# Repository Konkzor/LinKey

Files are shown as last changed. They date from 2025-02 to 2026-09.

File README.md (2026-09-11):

<p align="center">
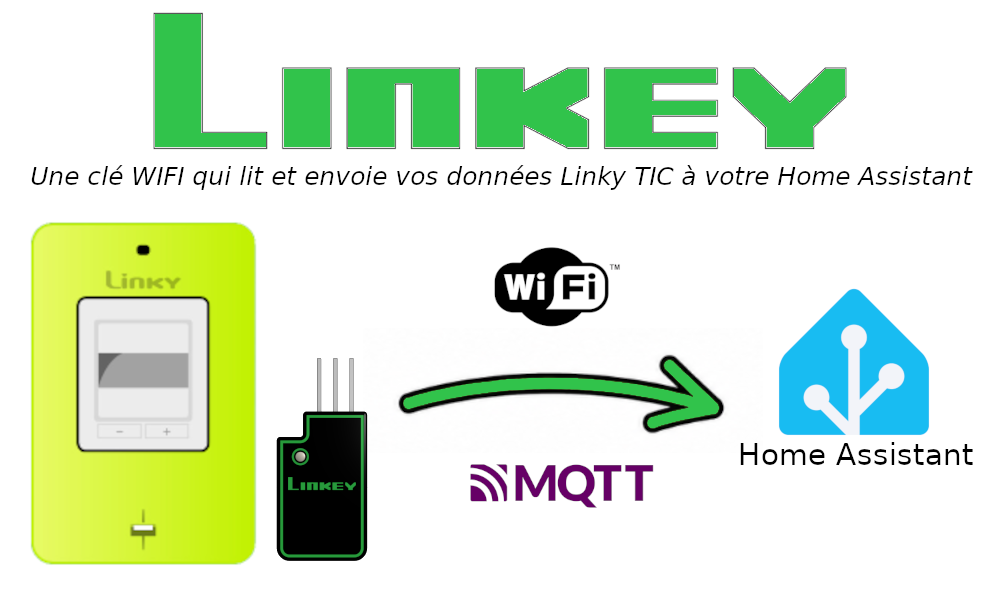
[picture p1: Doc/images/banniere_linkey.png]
Logo Linkey
  
</p>







Moniteur **open-hardware** basse consommation à base d'ESP32 pour le compteur électrique **Linky** (monophasé), avec intégration native à **Home Assistant** via MQTT.

LinKey (jeu de mot) lit la sortie série TIC (Télé-Information Client) d'un Linky monophasé et publie les mesures de puissance, d'énergie et de courant vers le broker MQTT de votre Home Assistant. Le coprocesseur ULP de l'ESP32 décode la trame TIC pendant que le CPU principal reste en *light sleep*, ce qui maintient une consommation moyenne suffisamment faible pour fonctionner sur l'alimentation de la TIC via une supercapa.

## Fonctionnalités

- Décodage UART 7E1 (1200 bauds) par le coprocesseur ULP de l'ESP32
- Boucle principale en *light sleep* avec *modem sleep* WiFi
- Publication MQTT en QoS 1, *Last Will and Testament* et auto-découverte Home Assistant
- Alimentation par supercapa avec surveillance de tension intégrée
- Retour visuel par LED RGB
- Compatible contrats BASE, HP/HC, Tempo et EJP
- Mode TIC historique (standard à venir)

## Structure du dépôt

```
.
├── CAO/        Boîtier imprimable 3D (source STEP + modèle Onshape)
├── Doc/        Spécification TIC Linky et documents de référence
├── Firmware/   Projet ESP-IDF (ULP + machine d'état CPU, WiFi/MQTT)
└── PCB/        Projet KiCad, schéma, Gerbers

```

## Documentation

- [Guide du firmware](Firmware/README.md) — compilation, flashage, configuration, topics MQTT, découverte HA
- [Guide de la carte (PCB)](PCB/README.md) — composants, brochage ESP32, connexion TIC, fabrication
- [Guide du boîtier (CAO)](CAO/README.md) — source Onshape, STEP, paramètres d'impression
- [Spécification TIC Linky](Doc/Enedis-MOP-CPT_002E.pdf) — document de référence Enedis

## Firmware

Le firmware est un projet ESP-IDF situé dans [`Firmware/`](Firmware/). Consultez [`Firmware/README.md`](Firmware/README.md) pour le guide complet de compilation, flashage et configuration.

Démarrage rapide :

```bash
git clone --recurse-submodules https://github.com/Konkzor/LinKey.git
cd LinKey/Firmware
source ~/esp/v5.4.1/esp-idf/export.sh
idf.py menuconfig    # Configurer l'appareil et les options MQTT
idf.py -p /dev/ttyUSB0 flash monitor
```

Les identifiants WiFi sont provisionnés ensuite en BLE via l'application Espressif. Le firmware tente de découvrir Home Assistant en mDNS pour construire automatiquement l'URI MQTT (`mqtt://<ha-ip>:1883`), puis utilise `mqtt://homeassistant.local:1883` comme solution de repli.

L'identité MQTT par défaut est dérivée de l'adresse MAC WiFi : utilisateur `linkey_<suffixe_mac>` et topics `linkey/<suffixe_mac>/...`, par exemple `linkey/8ebde0/state`.

## PCB

Le PCB a été réalisé sous KiCad 9.

<p align="center">
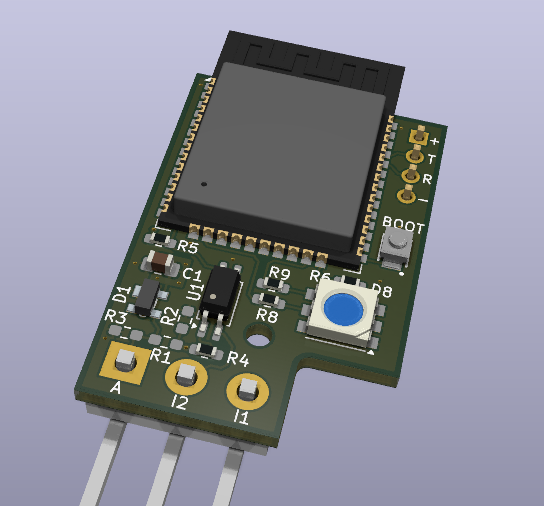
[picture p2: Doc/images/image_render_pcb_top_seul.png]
Rendu 3D de la carte LinKey
  
</p>

Les sources de la carte se trouvent dans [`PCB/`](PCB/). Voir [`PCB/README.md`](PCB/README.md) pour une description des composants, le brochage de l'ESP32 et la connexion TIC.

- Projet KiCad : [`PCB/LinKey.kicad_pro`](PCB/LinKey.kicad_pro)
- Modèles 3D de certains composants : [`PCB/MCAD files/`](PCB/MCAD%20files/)

> Note : Les fichiers de fabrication et la nomenclature ne sont pas versionnés dans le repo. Ils sont disponibles en artefacts des jobs de la CI ainsi que dans la [page Releases](https://github.com/Konkzor/LinKey/releases) pour les versions taguées.

## CAO

Le boîtier est conçu sous Onshape et imprimable en 3D.

<p align="center">
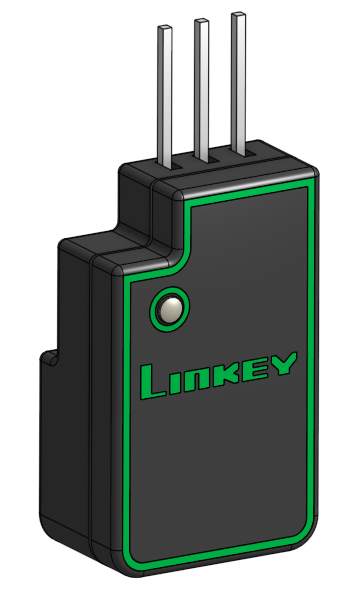
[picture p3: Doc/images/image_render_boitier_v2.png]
Rendu 3D du boîtier LinKey v2
  
</p>

Les sources se trouvent dans [`CAO/`](CAO/). Voir [`CAO/README.md`](CAO/README.md) pour le lien vers le modèle Onshape et les paramètres d'impression conseillés.

- Source CAO neutre (STEP) ;
- Fichiers prêts à imprimer (3MF multicolore, STL mono-couleur) : [page Releases](https://github.com/Konkzor/LinKey/releases).

## Licence

Ce projet utilise une **double licence** selon la nature des fichiers :

### Matériel — CERN-OHL-W-2.0

Le matériel (`PCB/` : sources KiCad, Gerbers… et `CAO/` : modèles 3D du boîtier, pièces mécaniques) est distribué sous **CERN Open Hardware Licence Version 2 – Weakly Reciprocal (CERN-OHL-W-2.0)**.

Vous êtes libre d'utiliser, d'étudier, de modifier et de fabriquer ce matériel.
Si vous modifiez les fichiers de conception eux-mêmes, vous devez publier ces modifications sous la même licence.
En revanche, vous n'êtes pas tenu de publier les sources de produits plus larges qui ne font qu'incorporer cette conception.

Texte complet : [`LICENSE`](LICENSE) (EN).

### Firmware — MIT

Le code du firmware (`Firmware/main/`) est distribué sous **licence MIT**, plus permissive et adaptée au logiciel.

Texte complet : [`Firmware/LICENSE`](Firmware/LICENSE) (EN).

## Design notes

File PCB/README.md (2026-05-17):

# LinKey — Carte électronique

<p align="center">
  Rendu 3D de la carte LinKey
</p>

Sources matérielles de la carte LinKey : projet KiCad, Gerbers et nomenclature.

> [!NOTE]
> La révision PCB est portée par les **tags git** `pcb-v*` (ex. `pcb-v1.0`). C'est la **source unique** : la CI dérive la version d'`git describe --tags --match 'pcb-v*'` et l'injecte à la fois dans le nom de l'artefact (`LinKey-pcb-<version>-fab`) et dans la variable de projet `PCB_VERSION` (Board Setup → Text Variables) pour que la sérigraphie `${PCB_VERSION}` reflète exactement l'état du dépôt :
>
> | Build | `${PCB_VERSION}` et nom d'artefact |
> |-------|------------------------------------|
> | Local (export manuel depuis KiCad) | `UNCONTROLLED` — valeur fixée en dur dans [`LinKey.kicad_pro`](LinKey.kicad_pro), signale que les fichiers de fab n'ont pas été produits par la CI et ne doivent pas être utilisés |
> | CI hors tag | `vX.Y-N-gSHA` (tag le plus récent + commits depuis + hash court) |
> | CI sur un tag `pcb-vX.Y` | `vX.Y` |

## Couche physique de la TIC Linky

> Source : [Enedis-NOI-CPT_54E](../Doc/Enedis-MOP-CPT_002E.pdf), §5.3.1 *Caractéristiques des signaux* (Table 3).

La sortie TIC du compteur Linky se présente sur le bornier client sous forme de **trois bornes** (`I1`, `I2`, `A`) : la paire `I1`/`I2` véhicule les **données**, et la paire `I1`/`A` est dédiée à l'**alimentation parasite** des récepteurs. Le compteur émet sur ce bus un **signal binaire modulé par tout-ou-rien sur une porteuse 50 kHz ± 3 %** (Table 3 de la spec Enedis), avec une **logique de codage négative** (porteuse présente ⇒ « 0 », porteuse absente ⇒ « 1 ») et une transmission **unidirectionnelle**.

<p align="center">
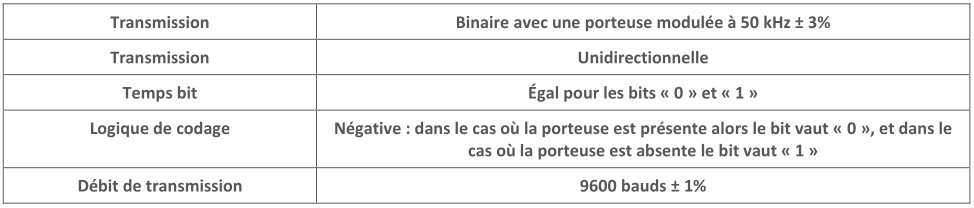
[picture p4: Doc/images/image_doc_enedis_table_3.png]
Enedis — Table 3 : Caractéristiques des signaux
  
</p>

> [!WARNING]
> Bien que les niveaux soient bas, le bus TIC reste relié au compteur — une **isolation galvanique côté récepteur reste obligatoire** pour la sécurité utilisateur et la conformité. C'est le rôle de l'optocoupleur (voir l'étage d'entrée ci-dessous).

Le bus est connecté à la carte via le connecteur **`J1`** (Samtec **HPM-03-04-T-S**, header 3 broches, pas 5 mm, sortie à angle droit).

## Architecture du PCB

L'architecture du PCB est composée de 2 branches principales :

```mermaid
flowchart LR
    TIC([TIC Linky J1<br/>I1, I2, A])

    TIC -->|I1 / A| D1[Pont redresseur<br/>D1]
    D1 --> Charge[Circuit de charge<br/>Q1, Q2, U4]
    Charge --> C2[(C2 — 1 F<br/>supercapa)]
    C2 --> Boost[Boost 3,3 V<br/>U5 — TPS61022]
    Boost --> ESP[ESP32 WROOM-32E<br/>+ périphériques]

    TIC -->|I1 / I2| U1[Opto AC/DC<br/>U1 — ACPL-214]
    U1 -->|RX — GPIO 14| ESP

    C2 -.->|ADC GPIO 33 — V_cap| ESP
```

- **Branche supérieure** : chemin d'alimentation, sur les bornes **`I1` / `A`** du Linky → pont redresseur → circuit de charge supercapa → `C2` → boost 3,3 V → ESP32.
- **Branche inférieure** : chemin de données, sur les bornes **`I1` / `I2`** du Linky → optocoupleur → ESP32.

Remarque : En **trait pointillé** la mesure de la tension du supercondensateur par l'ESP32.

### 1. Étage d'entrée

Sépare et conditionne les deux fonctions du bus TIC.

- **Démodulation des données** — `U1` (Broadcom **ACPL-214-500E**, opto **AC** SOP-4) extrait directement l'enveloppe de la porteuse 50 kHz et fournit un signal UART démodulé côté ESP32 (pull_up `R5` incluse), tout en assurant l'isolation galvanique.
- **Pont redresseur d'alimentation** — `D1` (Infineon **BAS 4002A RPP E6327**, array de Schottky basse Vf) forme un pont à quatre diodes dans un seul boîtier qui rectifie la porteuse 50 kHz pour alimenter le reste de la carte.

<p align="center">
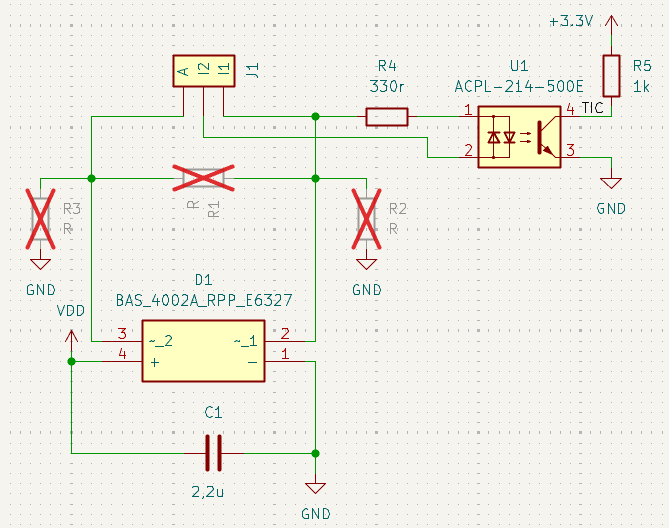
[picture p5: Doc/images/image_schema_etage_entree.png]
Schéma de l'étage d'entrée (opto + pont redresseur)
  
</p>

### 2. Circuit de charge du supercondensateur

Stocke l'énergie disponible pour absorber les pics de consommation pendant l'émission WiFi/MQTT. Limite le courant et la tension de charge.

- **Supercondensateur** — `C2` (KYOCERA AVX **SCCR12E105SRB**, 1 F / 3 V, ESR faible, radial 8×12 mm).
- Limitation de courant et tension contrôlant la tension Vgs de `Q2` (TI **CSD25402Q3A**, P-MOSFET 20 V) :
  - **Limitation de courant** — `Q1` (ON Semi **MMBT2907A**, PNP 60 V / 0,6 A) conjugué à `R10` (10 Ω) qui fixe le seuil de courant débité par l'étage d'entrée vers la supercapa à environ  40 mA.
  - **Limitation de tension** — `U4` (TI **TL431**, référence shunt ajustable) clampe la tension de charge à 2,7V de la supercapa (seuil réglé par `R15` et `R16`).

<p align="center">
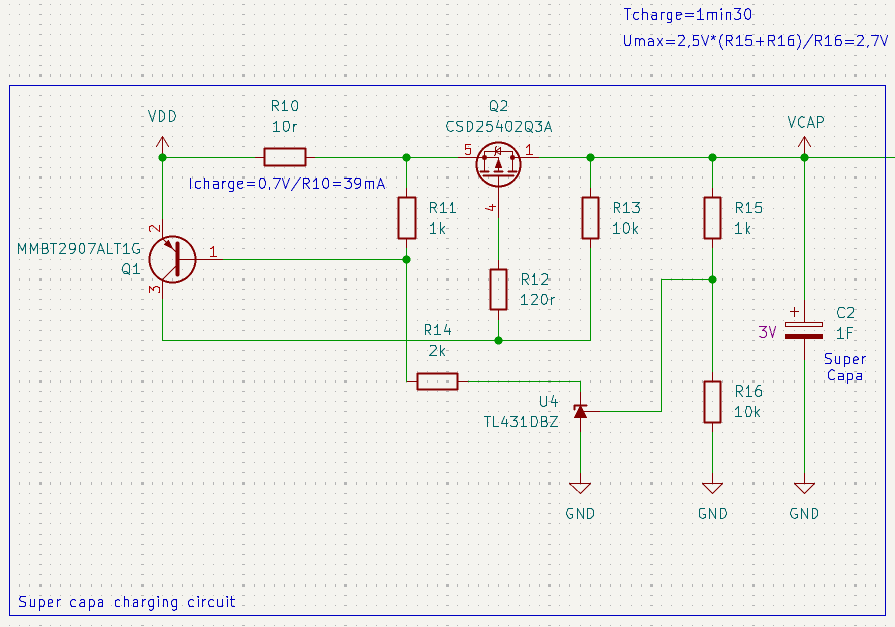
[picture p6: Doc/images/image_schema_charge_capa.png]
Schéma du circuit de charge du supercondensateur
  
</p>

### 3. Alimentation 3,3 V (boost)

Convertit la tension variable du supercondensateur (0 V → 2,7 V) en un rail 3,3 V stable pour l'ESP32.

- **Convertisseur** — `U5` (TI **TPS61022**, boost synchrone 8 A pic, **démarrage à 1,5 V, maintien jusqu'à 0,5 V**) : on peut tirer du jus de la supercapa presque jusqu'à le vider complètement.
- **Inductance** — `L1` (Coilcraft **XEL5030-102MEC**, 1 µH), recommandée par TI.
- **Capacités** — `C3`, `C4` pour l'entrée, `C6` (22 µF / 10 V X7R 1206) pour la sortie.
- **Pont diviseur** — `R17` (453 k) / `R18` (100 k) pour régler la sortie à 3,3 V.

<p align="center">
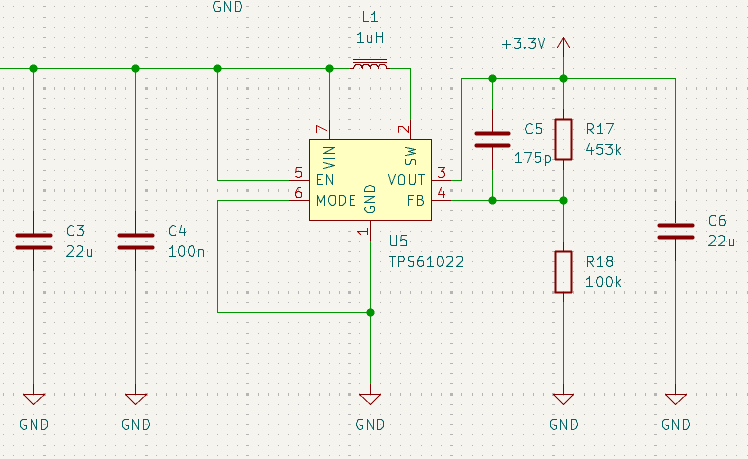
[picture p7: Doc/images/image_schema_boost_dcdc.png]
Schéma du convertisseur boost 3,3 V (TPS61022)
  
</p>

### 4. ESP32 et périphériques

- **MCU** — `U2` (Espressif **ESP32-WROOM-32E-N8**, 8 MB flash SPI, antenne PCB intégrée). Module choisi pour sa disponibilité du **coprocesseur ULP** que le firmware utilise pour décoder la TIC pendant le *light sleep*.
- **Découplage** — `C8` (100 nF), `C7` (22 µF).
- **Interface programmation/debug** — `J2` (header 4 broches, pas 2,54 mm) expose `TX`, `RX`, `GND`, `3V3` pour le flashage et le debug.
- **Boutons** — deux boutons tactiles Omron **B3U-1000P** :
  - `SW1` — **RESET**, raccordé sur la broche `EN` de l'ESP32 (tient le module en reset tant qu'il est pressé).
  - `SW2` — **BOOT**, raccordé sur `IO0` ; à maintenir pendant un reset pour entrer en mode flashage.
- **LED d'état RGB** — `D8` (American Bright **BL-HBXJXGX32L**, 5050 PLCC6) avec ses résistances de limitation `R6` (120 Ω) / `R8` (330 Ω) / `R9` (120 Ω) sur les trois canaux B/R/G respectivement. Pilotée par GPIO 2 / 13 / 15 ; flash bref de 10 ms à chaque itération de la FSM (voir `Firmware/README.md`).

<p align="center">
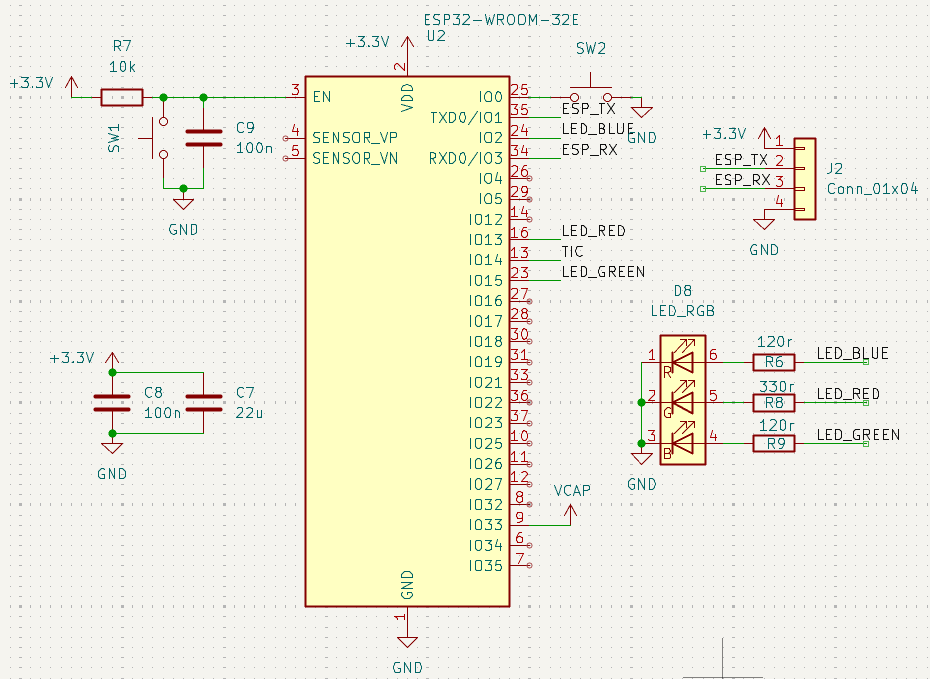
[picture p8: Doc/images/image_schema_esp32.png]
Schéma de l'ESP32 et de ses périphériques (LED RGB, bouton, header debug)
  
</p>

## Affectation des broches (ESP32)

| Fonction | GPIO |
|---|---|
| RX TIC Linky | 14 |
| ADC tension supercondensateur | 33 |
| LED RGB Rouge | 13 |
| LED RGB Verte | 15 |
| LED RGB Bleue | 2 |
| RX UART ESP | 3 |
| TX UART ESP | 1 |

## Contenu du dossier

| Fichier / dossier | Description |
|---|---|
| [`LinKey.kicad_pro`](LinKey.kicad_pro) | Projet KiCad 9 |
| [`LinKey.kicad_sch`](LinKey.kicad_sch) | Schéma |
| [`LinKey.kicad_pcb`](LinKey.kicad_pcb) | Routage |
| [`fab-output.kicad_jobset`](fab-output.kicad_jobset) | Jobset KiCad décrivant les sorties de fabrication générées en CI |
| [`MCAD files/`](MCAD%20files/) | Modèles 3D des composants (STEP) |
| [`LinKey_Lib_Footprints.pretty/`](LinKey_Lib_Footprints.pretty/) | Bibliothèque d'empreintes du projet |
| [`LinKey_Lib_Symbols.kicad_sym`](LinKey_Lib_Symbols.kicad_sym) | Bibliothèque de symboles du projet |

## Fabrication

Les fichiers de fabrication ne sont **pas versionnés** : ils sont régénérés à chaque push par le workflow GitHub Actions [`.github/workflows/ci.yml`](../.github/workflows/ci.yml) (job `pcb-fab`) à partir du jobset [`fab-output.kicad_jobset`](fab-output.kicad_jobset), et publiés en tant qu'artefact nommé **`LinKey-pcb-<PCB_VERSION>-fab`** sur l'exécution correspondante (la version provient de la variable de projet `PCB_VERSION` — cf. note en haut de ce README).

Contenu de l'artefact :

| Fichier | Description |
|---|---|
| `gerbers/LinKey-F_Cu.gbr`, `B_Cu.gbr`, `In1_Cu.gbr`, `In2_Cu.gbr` | Couches cuivre (4 couches) |
| `gerbers/LinKey-F_Mask.gbr`, `B_Mask.gbr` | Masques de soudure |
| `gerbers/LinKey-F_Paste.gbr`, `B_Paste.gbr` | Pochoir pâte à braser |
| `gerbers/LinKey-F_Silkscreen.gbr`, `B_Silkscreen.gbr` | Sérigraphies |
| `gerbers/LinKey-Edge_Cuts.gbr` | Contour de la carte |
| `gerbers/LinKey-job.gbrjob` | Métadonnées Gerber X2 (stackup) |
| `LinKey-PTH.drl`, `LinKey-NPTH.drl` | Perçages (plaqués / non plaqués) |
| `LinKey_positions-all.csv` | Fichier de positions (pick & place) |
| `LinKey_Bill_of_Materials.csv` | Nomenclature (BOM) |

Pour récupérer l'archive : ouvrir l'exécution CI sur GitHub → onglet *Summary* → section *Artifacts* → **`LinKey-pcb-<PCB_VERSION>-fab`**.

## Consommation

- ***Light sleep*** : à mesurer
- **Actif (publication)** : à mesurer
- **Moyenne** : à mesurer

## Licence

Voir le fichier [LICENSE](../LICENSE) à la racine du dépôt (CERN-OHL-W-2.0).

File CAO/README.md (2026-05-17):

# LinKey — Boîtier

<p align="center">
  Rendu 3D du boîtier LinKey v2
</p>

Boîtier imprimable en 3D pour la carte LinKey.

## Source du modèle

Le boîtier est conçu et versionné sous **Onshape**, publiquement accessible ici :

- 🔗 **Modèle Onshape** : [Linkey - boitier 3D - top & bottom](https://cad.onshape.com/documents/5972464b754aa87349b49170/w/c061eca082e853c5ff9cc07a/e/9dccff000b4ae340905eef1a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)
- Un export .STEP de la dernière version est également versionné dans ce repo.

## Téléchargements (fichiers prêts à imprimer)

2 versions de boîtiers sont disponibles au téléchargement :
- Une version d'origine bi-couleur pour les imprimantes compatibles ;
- Une version simplifiée (= retrait des liserés verts sur la face top) monochrome pour les imprimantes ne supportant pas l'impression multicolore.

Les fichiers prêts à imprimer sont attachés à la **[page Releases du dépôt](https://github.com/Konkzor/LinKey/releases)** :

| Fichier | Format | Utilisation |
|---|---|---|
| `Linkey-boitier-<vx>-top-et-bottom-bicouleur.3mf` | 3MF | Imprimantes multi-matériaux (AMS) |
| `Linkey-boitier-<vx>-top.stl` | STL | Casing top — imprimante mono-extrudeur |
| `Linkey-boitier-<vx>-bottom.stl` | STL | Casing bottom — imprimante mono-extrudeur |

## Impression

<p align="center">
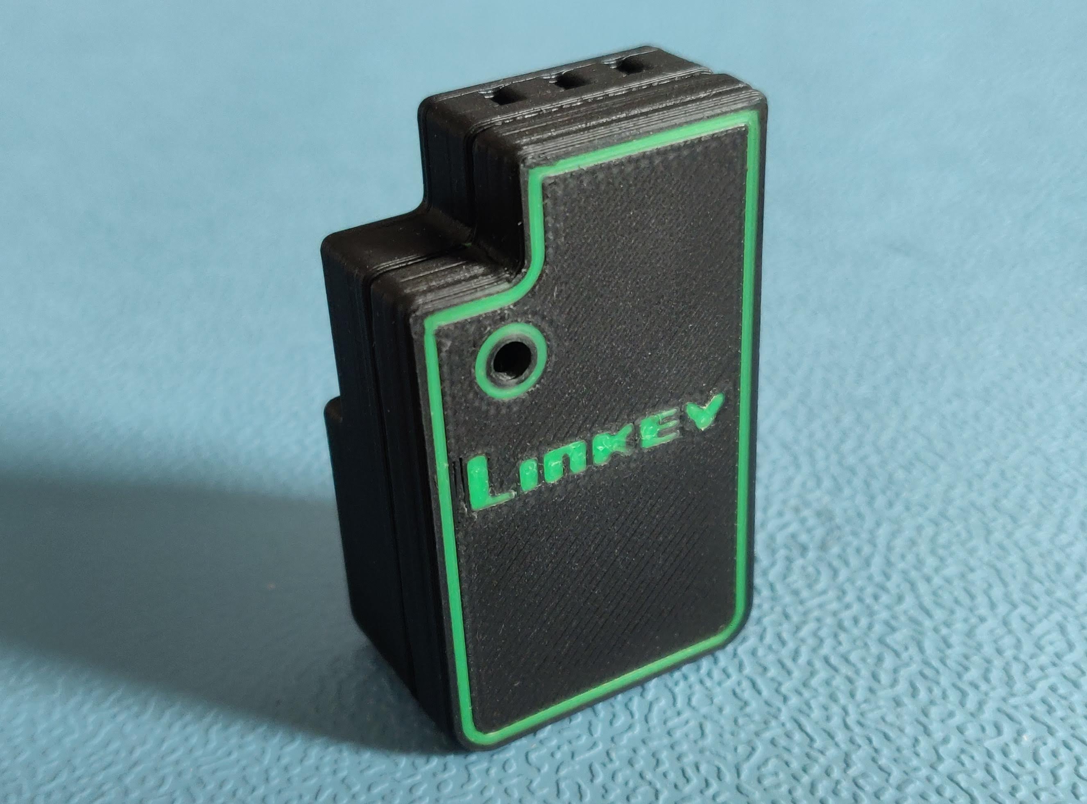
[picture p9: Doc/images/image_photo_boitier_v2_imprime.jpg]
Photo d'un boîtier LinKey imprimé
  
</p>

Paramètres testés sur le tirage ci-dessus (à ajuster selon votre imprimante / slicer) sur une imprimante Bambu Lab P2S et Bambu Studio :

| Paramètre | Valeur |
|---|---|
| Matériau | PLA |
| Hauteur de couche | 0,16 mm |
| Remplissage | 15 % |
| Orientation | Extérieur du boîtier vers le haut (idem au .3mf) |
| Supports | Activé |
| Buse | 0,4 mm |

<p align="center">
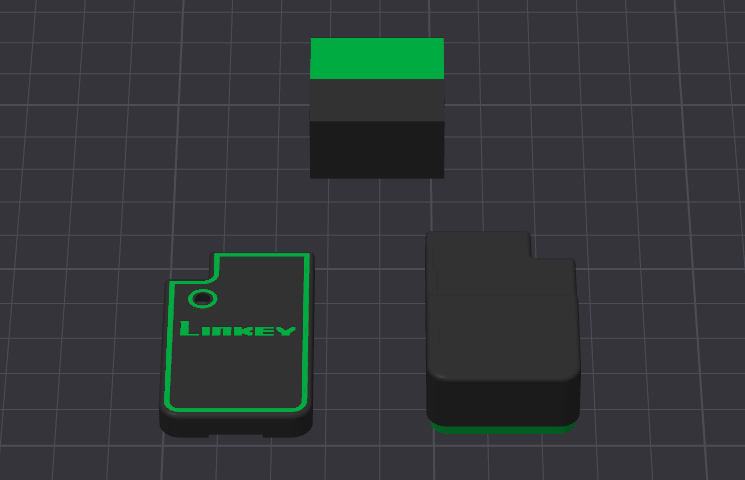
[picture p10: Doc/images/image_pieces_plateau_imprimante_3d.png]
Capture d'écran Bambu Studio
  
</p>

## Contenu du dossier

> [!NOTE]
> Les fichiers `.3mf` et `.stl` ne sont **pas versionnés dans le dépôt** : ce sont des artefacts dérivés du modèle Onshape. Ils sont publiés dans la [page Releases](https://github.com/Konkzor/LinKey/releases) pour chaque révision du boîtier.

## Licence

Voir le fichier [LICENSE](../LICENSE) à la racine du dépôt (CERN-OHL-W-2.0).

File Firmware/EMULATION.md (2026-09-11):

# Émulation du firmware LinKey

Ce README décrit la cible d'émulation QEMU du firmware LinKey.

L'émulation est activée par le build via `LINKEY_QEMU_EMULATION=ON`. Elle fournit les dépendances matérielles nécessaires à l'exécution dans QEMU via des mocks au link, tout en exécutant la logique applicative du firmware.

## Conception

Le build d'émulation ajoute le composant `Firmware/emulation/` et wrappe les fonctions liées au matériel au link :

- les lectures de tension retournent une tension de supercondensateur constante ;
- les appels WiFi initialisent QEMU OpenETH ;
- MQTT utilise le chemin `mqtt_manager.c` et se connecte à l'URI du broker QEMU ;
- l'enregistrement du callback ULP est remplacé par la mémorisation de la tâche principale à notifier ;
- une tâche FreeRTOS d'émulation écrit périodiquement une trame TIC (constante) dans les buffers RTC et notifie la tâche principale ;
- les trames TIC de test sont écrites dans les buffers RTC lus par `get_linky_data()`.

La configuration spécifique à QEMU est portée par `emulation/sdkconfig.qemu.defaults` et par l'option CMake `LINKEY_QEMU_EMULATION`.

## Couverture d'émulation

| Domaine | Élément | Statut | Commentaire |
| --- | --- | --- | --- |
| LINKY | Interface TIC historique | 🟡 | Format historique exercé par les trames mockées. |
| LINKY | Interface TIC standard | 🔴 | Non supportée par le firmware actuel. |
| LINKY | Trame TIC tarifaire BASE | 🟢 | Sélectionnée par défaut avec `--tariff_option base`. |
| LINKY | Trame TIC tarifaire HPHC | 🟢 | Sélectionnée avec `--tariff_option hphc`. |
| LINKY | Trame TIC tarifaire EJP | 🟢 | Sélectionnée avec `--tariff_option ejp`. |
| LINKY | Trame TIC tarifaire TEMPO | 🟢 | Sélectionnée avec `--tariff_option tempo`. |
| LINKY | Déconnexion / reconnexion TIC | 🔴 | Aucun scénario de perte TIC injecté aujourd'hui. |
| LINKY | Données électriquement cohérentes | 🔴 | Trame constante; intensité, puissance et index ne forment pas un profil physique. |
| Hardware / PCB | Interface TIC physique | 🔴 | Pas de validation optocoupleur, niveaux électriques, inversion ou bruit de ligne. |
| Hardware / PCB | Tension supercondensateur | 🟡 | Lecture mockée à une valeur constante. |
| Hardware / PCB | Profil charge / décharge supercondensateur | 🔴 | Pas de rampe ni de scénario brownout progressif. |
| Hardware / PCB | Chemin basse tension firmware | 🟡 | Les fonctions sont appelées, mais avec une tension constante. |
| Hardware / PCB | LED / GPIO de statut | 🟡 | Les GPIO sont initialisées par le firmware; aucune LED physique ou rendu visuel. |
| ESP32 / firmware | Boot ESP32 | 🟢 | Exécuté sous QEMU avec image flash générée. |
| ESP32 / firmware | FreeRTOS | 🟢 | Scheduler et tâches firmware réels. |
| ESP32 / firmware | Logique applicative | 🟢 | FSM, parsing et publication utilisent le code firmware. |
| ESP32 / firmware | MQTT | 🟢 | Client MQTT réel via la pile ESP-IDF; nécessite le broker local. |
| ESP32 / firmware | Réseau | 🟡 | WiFi remplacé par QEMU OpenETH. |
| ESP32 / firmware | Radio WiFi réelle | 🔴 | Pas d'association WiFi, RSSI, pertes radio ou credentials AP. |
| ESP32 / firmware | ULP | 🟡 | Remplacé par une tâche FreeRTOS qui écrit les buffers RTC et notifie la tâche principale. |
| ESP32 / firmware | Programme ULP réel | 🔴 | Le coprocesseur ULP et son programme assembleur ne sont pas exécutés. |
| ESP32 / firmware | Power management / light sleep | 🔴 | `esp_pm_configure()` est wrappé; consommation et timing sleep non représentatifs. |
| ESP32 / firmware | NVS / timers / logs | 🟢 | Composants ESP-IDF exercés dans l'environnement QEMU. |

Légende : `🟢` exercé, `🟡` partiellement émulé, `🔴` non émulé.

## Fichiers

```text
Firmware/
  emulation/
    CMakeLists.txt            Composant ESP-IDF d'émulation
    linkey_qemu_mocks.c       Mocks QEMU par wrapping au link
    qemu_test_data.h          Trames TIC déterministes
    sdkconfig.qemu.defaults   Paramètres sdkconfig réservés à QEMU
  run_qemu_linkey.sh          Lanceur QEMU pour les artefacts build-qemu-*
```

## Build

Depuis `Firmware/` :

```bash
mkdir -p build-qemu-base
printf '%s\n' 'CONFIG_LINKEY_TARIFF_BASE=y' > build-qemu-base/sdkconfig.tariff.defaults

idf.py -B build-qemu-base \
  -DSDKCONFIG=build-qemu-base/sdkconfig \
  '-DSDKCONFIG_DEFAULTS=sdkconfig.defaults;emulation/sdkconfig.qemu.defaults;build-qemu-base/sdkconfig.tariff.defaults' \
  -DLINKEY_QEMU_EMULATION=ON \
  -DLINKEY_QEMU_TARIFF_OPTION=BASE \
  build
```

Le lanceur utilise par défaut un build séparé par option tarifaire :
`build-qemu-base/`, `build-qemu-hphc/`, `build-qemu-ejp/` ou `build-qemu-tempo/`.

## Exécution

Après le build :

```bash
./run_qemu_linkey.sh
```

Le lanceur utilise les artefacts du build QEMU correspondant à l'option tarifaire sélectionnée.

Options utiles :

```bash
./run_qemu_linkey.sh --build      # build d'abord, puis lance QEMU
./run_qemu_linkey.sh --monitor    # expose le moniteur QEMU sur 127.0.0.1:55555
./run_qemu_linkey.sh --debug      # écrit les logs de debug QEMU dans qemu_debug.log
./run_qemu_linkey.sh --tariff_option hphc
```

Options tarifaires supportées :

```text
base, hphc, ejp, tempo
```

Sans `--tariff_option`, `base` est utilisée.
L'option sélectionne à la fois la trame TIC mockée et la configuration firmware `CONFIG_LINKEY_TARIFF_*`.
La trame est constante. Les données ne sont pas forcément "électriquement" cohérentes.

## Broker MQTT

MQTT utilise le gestionnaire MQTT du firmware. Démarrer le broker local avant QEMU permet de valider la publication de bout en bout.

```bash
docker compose up -d mosquitto
```

Pour observer les messages publiés par le firmware émulé :

```bash
mosquitto_sub -h localhost -p 1884 -u linkey_ddeeff -P mqtt-password -t "linkey/#" -v
```

Cette commande se connecte au broker local exposé sur le port `1884`, s'abonne à tous les topics sous `linkey/` et affiche chaque message reçu avec son topic. Le broker QEMU refuse les connexions anonymes et attend les identifiants dérivés de la MAC mockée : `linkey_ddeeff` / `mqtt-password`.

L'URI du broker QEMU est définie dans `emulation/sdkconfig.qemu.defaults`.

## Validation

Commandes de validation :

```bash
mkdir -p build-qemu-base
printf '%s\n' 'CONFIG_LINKEY_TARIFF_BASE=y' > build-qemu-base/sdkconfig.tariff.defaults

idf.py -B build-qemu-base \
  -DSDKCONFIG=build-qemu-base/sdkconfig \
  '-DSDKCONFIG_DEFAULTS=sdkconfig.defaults;emulation/sdkconfig.qemu.defaults;build-qemu-base/sdkconfig.tariff.defaults' \
  -DLINKEY_QEMU_EMULATION=ON \
  -DLINKEY_QEMU_TARIFF_OPTION=BASE \
  build

idf.py build
```

Le premier build valide la cible QEMU. Le second valide le build firmware standard.

## Extension des tests

Les extensions propres à l'émulation se placent dans `Firmware/emulation/`.

Ajouts possibles :

- un générateur de trames TIC "cohérentes" (en puissance, incrémentation des index, dépassement, etc.) ;
- plusieurs scénarios de trames TIC ;
- profils de tension pour tester les transitions basse tension ;
- injection d'échecs de publication MQTT ;
- simulation de timeout ULP.

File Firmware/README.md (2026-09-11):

# Firmware Linkey

## Vue d'ensemble

Ce firmware utilise le coprocesseur ULP (*Ultra Low Power*) de l'ESP32 pour surveiller en continu la sortie série TIC (Télé-Information Client) du Linky (monophasé) pendant que le CPU principal reste en *light sleep*. L'ULP reçoit chaque trame TIC complète dans un buffer RTC, puis réveille le CPU principal pour publier les données via MQTT.

```
┌─────────────────────────────────────────────┐
│  CPU principal (init + FSM)                 │
│  Réveil périodique                          │
│  • Surveillance tension avec seuils de      │
│    fallback par état                        │
│  • Provisioning WiFi BLE si nécessaire      │
│  • Gestion des connexions WiFi/MQTT         │
│  • Auto-découverte HA à la connexion MQTT   │
│  • Publication JSON des données capteurs    │
│  • Modem sleep + scaling de fréquence CPU   │
└─────────────────────────────────────────────┘
                    ▲
                    │
                    │
┌─────────────────────────────────────────────┐
│  Coprocesseur ULP (toujours actif)          │
│  • Bit-bang UART à 1200 bauds (7E1)         │
│  • Trame complète (ETX) en double buffer    │
│  • Tourne en continu                        │
└─────────────────────────────────────────────┘
```

## Fonctionnalités

- **Vrai support UART 7E1** : gestion correcte des 7 bits de données + parité paire (ignorée)
- **Mode *light sleep*** : WiFi maintenu connecté, réveil rapide (à mesurer)
- **WiFi** :
  - Identifiants provisionnés en BLE via l'application Espressif
  - Stockage des identifiants dans la NVS WiFi ESP-IDF
  - Validation WiFi différée : la FSM reprend la main après le provisioning
  - Scan WiFi désactivé pendant le provisioning pour limiter le courant
  - Mise en cache du BSSID/canal pour reconnexion instantanée
  - *Fast scan*
  - *Modem sleep* WiFi pour économie d'énergie
  - IP statique optionnelle (court-circuite le DHCP)
- **MQTT** :
  - Découverte automatique du broker Home Assistant via mDNS (`_home-assistant._tcp.local`). Port imposé 1883.
  - QoS 1 pour une livraison fiable et une meilleure détection des coupures WiFi
  - Délais d'expiration courts
  - *Last Will and Testament* (LWT) pour le suivi de disponibilité
  - Info de debug envoyées au broker :
     - `VCAP` : tension du supercondensateur (millivolts)
     - `uptime` : temps de fonctionnement (secondes)
- **Intégration Home Assistant** :
  - Auto-découverte MQTT (payload unique)
  - Suivi de disponibilité (online/offline)
  - Icônes et *state classes* personnalisés pour des statistiques HA correctes
- **Réception trame par trame** : l'ULP reçoit une trame TIC complète (terminée par ETX `0x03`) en double buffer RTC ping-pong, puis réveille le CPU
- **Validation de checksum** : vérifie le checksum TIC Linky `(sum & 0x3F) + 0x20`
- **Statut LED RGB** : flash bref (10 ms) à chaque itération de la FSM, couleur dépendant de l'état courant — la LED reste éteinte le reste du temps pour économiser l'énergie
- **Provisioning manuel** : un appui long de plus de 2 s sur BOOT/GPIO0 force l'entrée en provisioning BLE sans effacer les identifiants WiFi existants
- **Surveillance tension supercondensateur** : lecture de la tension du condensateur
- **Logs de debug** : journalisation verbeuse configurable pour le diagnostic

## Fonctionnement

### Machine d'état (FSM)

```mermaid
stateDiagram-v2
    direction LR
    [*] --> WAIT_VOLTAGE
    WAIT_VOLTAGE --> BLE_PROVISION: V ≥ 2,5 V et WiFi non provisionné
    BLE_PROVISION --> WAIT_VOLTAGE: identifiants stockés / V faible
    WAIT_VOLTAGE --> ACTIVE: V ≥ 2,5 V et WiFi provisionné
    ACTIVE --> WAIT_VOLTAGE: V faible (fallback)
    ACTIVE --> BLE_PROVISION: BOOT/GPIO0 maintenu > 2 s

    state ACTIVE {
        direction LR
        [*] --> WIFI_CONNECT
        WIFI_CONNECT --> MQTT_CONNECT: WiFi OK
        MQTT_CONNECT --> WIFI_CONNECT: WiFi perdu
        MQTT_CONNECT --> WAIT_ULP_DATA: MQTT OK
        WAIT_ULP_DATA --> WIFI_CONNECT: WiFi/MQTT perdu
        WAIT_ULP_DATA --> PUBLISH_DATA: trame reçue
        PUBLISH_DATA --> WAIT_ULP_DATA: trame suivante
        PUBLISH_DATA --> MQTT_CONNECT: échec publication
        PUBLISH_DATA --> WIFI_CONNECT: WiFi perdu
    }
```

| État | Rôle | Couleur du flash LED |
|---|---|---|
| `WAIT_VOLTAGE` | Attend que le supercondensateur soit chargé (≥ 2,5 V) | Rouge |
| `BLE_PROVISION` | Provisioning BLE des identifiants WiFi, sans scan ni validation WiFi immédiate | Blanc |
| `WIFI_CONNECT` | Connexion WiFi (avec cache BSSID/canal), retry interne en cas d'échec | Bleu |
| `MQTT_CONNECT` | Connexion au broker MQTT + auto-découverte HA, retry interne si broker indisponible | Magenta |
| `WAIT_ULP_DATA` | Init ULP + attente d'une trame TIC complète, CPU en *light sleep* | Jaune |
| `PUBLISH_DATA` | Lecture buffer ULP, validation checksum (par groupe d'information), publication MQTT | Vert |

> **Fallback tension (`ACTIVE → WAIT_VOLTAGE`)** : dans tous les états regroupés sous `ACTIVE`, la FSM retombe vers `WAIT_VOLTAGE` si la tension descend sous `VOLTAGE_FALLBACK_MIN_MV` (1,5 V) **ou** chute de plus de 200 mV par rapport au pic atteint depuis l'entrée dans l'état (seuil dynamique). Les connexions WiFi/MQTT sont alors arrêtées.

L'initialisation NVS, LED, ADC et gestion d'énergie est effectuée une seule fois au démarrage, avant l'entrée dans la FSM. Elle n'a donc pas de flash LED dédié.

### Provisioning WiFi BLE

Si aucun identifiant WiFi n'est présent dans la NVS WiFi ESP-IDF, la FSM entre dans l'état `BLE_PROVISION` dès que la tension du supercondensateur est suffisante. Le service BLE apparaît sous le nom `Linkey_XXXXXX`, dérivé de l'adresse MAC.

Il est aussi possible de forcer le provisioning depuis les états actifs en maintenant BOOT/GPIO0 plus de 2 s. Cette demande arrête WiFi/MQTT et entre en `BLE_PROVISION`, mais ne supprime pas les identifiants WiFi déjà stockés. Si le provisioning manuel échoue alors que des identifiants existent encore, le firmware les conserve et retourne à `WAIT_VOLTAGE`.

Le provisioning utilise le protocole standard de l'application Espressif, avec les contraintes basse consommation suivantes :

- Le scan WiFi demandé par l'application est remplacé par une réponse vide. Il faut donc saisir le SSID manuellement.
- Les identifiants reçus sont enregistrés dans la NVS WiFi avec `esp_wifi_set_config()`.
- Le firmware répond ensuite à l'application comme si la connexion WiFi était validée, mais ne lance pas de connexion WiFi pendant le provisioning.
- Après succès, BLE/WiFi sont arrêtés et la FSM retourne à `WAIT_VOLTAGE`. La connexion WiFi réelle est effectuée plus tard par `WIFI_CONNECT`, sous contrôle des seuils de tension.
- Les anciens identifiants ne sont remplacés que lorsque l'application soumet de nouveaux identifiants. Ils ne sont pas effacés au moment d'entrer en provisioning manuel.

Le *Proof of Possession* est lu depuis la partition NVS `factory_data` quand elle est présente. Sinon, le firmware utilise le repli défini dans `factory_config_schema.h`, sauf override explicite via `menuconfig`.

Quand **Enable debug logging** est activé, le firmware imprime aussi un QR code compatible avec l'application Espressif dans le moniteur série. En usage normal, les informations de provisioning doivent venir de l'outil de flash factory, pas des logs firmware.

### Flash factory et informations d'installation

Le firmware contient une partition NVS dédiée `factory_data` pour les secrets propres à chaque appareil :

- `ble-pop` : PoP utilisé par l'application Espressif pour le provisioning WiFi BLE
- `mqtt-password` : mot de passe MQTT de l'utilisateur propre à l'appareil

Ces secrets sont générés et flashés par l'outil Python :

```bash
cd Firmware
python3 tools/factory_flash.py -p /dev/ttyUSB0
```

L'outil lit l'adresse MAC de l'ESP32, crée le dossier `factory/devices/<mac>/` si nécessaire, puis réutilise les mêmes secrets aux exécutions suivantes. Il génère la partition NVS factory, lance `idf.py build`, flashe le firmware, flashe `factory_data`, puis affiche les informations à recopier dans Home Assistant et dans un guide de démarrage rapide :

- nom BLE `Linkey_XXXXXX`
- contenu du QR code de provisioning et URL Espressif
- utilisateur MQTT `linkey_<suffixe_mac>`
- mot de passe MQTT
- préfixe de topic `linkey/<suffixe_mac>`

Pour préparer uniquement les fichiers sans flasher :

```bash
cd Firmware
python3 tools/factory_flash.py -p /dev/ttyUSB0 --no-flash
```

Les replis de développement et QEMU sont définis dans `factory_config_schema.h` : `linkey-pop` pour le PoP BLE et `mqtt-password` pour MQTT. Les champs `menuconfig` **Provisioning Proof of Possession** et **MQTT Password** sont seulement des overrides optionnels ; laissez-les vides pour utiliser ces replis ou la partition `factory_data` quand elle est flashée.

### Découverte du broker MQTT

Après la connexion WiFi, le firmware tente de découvrir Home Assistant via mDNS en interrogeant le service `_home-assistant._tcp.local`. Home Assistant annonce son service HTTP sur ce nom ; le firmware récupère l'adresse IP annoncée puis construit l'URI MQTT avec le port standard `1883` :

```text
_home-assistant._tcp.local -> 192.168.1.16
mqtt://192.168.1.16:1883
```

Si cette découverte échoue, le firmware utilise **MQTT Broker URI** comme repli. La valeur par défaut est `mqtt://homeassistant.local:1883`.

Le firmware ne se base pas sur `_mqtt._tcp.local` : ce service générique peut être annoncé par d'autres équipements du réseau (box, routeur, services internes) et ne désigne pas nécessairement le broker MQTT utilisé par Home Assistant.

La découverte ne fournit pas les identifiants MQTT. Si **MQTT Username** est laissé vide, le firmware utilise automatiquement `linkey_<suffixe_mac>`, où `<suffixe_mac>` correspond aux 6 derniers caractères hexadécimaux de l'adresse MAC WiFi. Exemple : `linkey_8ebde0`.

Si le broker exige une authentification, il faut donc créer cet utilisateur côté Home Assistant/Mosquitto, ou renseigner un autre nom dans **MQTT Username**. Le mot de passe MQTT est lu depuis la partition `factory_data` quand elle est présente ; sinon le firmware utilise le repli défini dans `factory_config_schema.h`, sauf override explicite par **MQTT Password**.

### Topics MQTT

Les topics ne sont pas configurables dans `menuconfig`. Ils sont dérivés automatiquement des 6 derniers caractères hexadécimaux de l'adresse MAC WiFi :

```text
linkey/<suffixe_mac>
```

Cela permet de connecter plusieurs clés linkey sur un même réseau sans configuration.

Exemple pour un suffixe `8ebde0` :

- `linkey/8ebde0/state` — payload JSON contenant les données capteurs (seules les valeurs valides sont incluses) :
  ```json
  {"iinst":3,"base":12345678,"papp":690,"adps":30,"vcap":2850,"uptime":3600}
  ```
- `linkey/8ebde0/status` — disponibilité de l'appareil (`online`/`offline` via LWT)
- `linkey/8ebde0/debug/request` — demande de publication de trame TIC brute
- `linkey/8ebde0/debug/tic_frame` — trame TIC brute publiée à la demande

**Note** : seules les valeurs Linky issues d'un groupe d'information avec un checksum valide **et qui ont changé depuis la dernière publication** sont incluses dans le JSON. `VCAP` et `uptime` sont toujours présents. Les index spécifiques à un tarif (HCHC/HCHP, EJPHN/EJPHPM, BBRH*) n'apparaissent que si le compteur est configuré avec le contrat correspondant.

### Home Assistant

L'appareil est auto-découvert via MQTT. À la connexion, un payload de découverte unique est publié sur :
```
homeassistant/device/linkey_<mac>/config
```

Cela enregistre l'appareil avec tous ses capteurs dans Home Assistant. Il est alors listé parmi les appareils de votre intégration MQTT :

<p align="center">
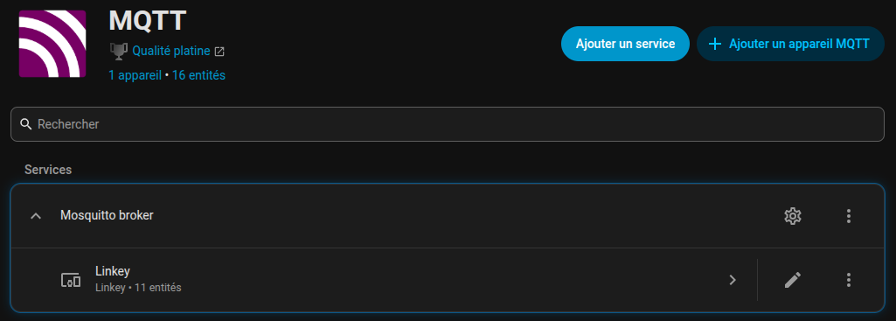
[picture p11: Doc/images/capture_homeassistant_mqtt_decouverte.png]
Capture écran HA découverte
  
</p>

En cliquant dessus, vous pouvez obtenir les "Informations Appareil" de celui-ci :

<p align="center">
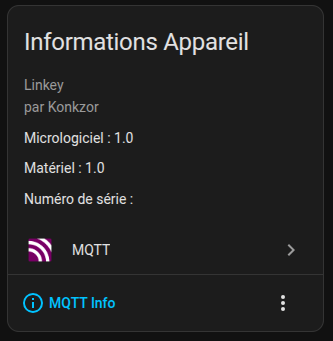
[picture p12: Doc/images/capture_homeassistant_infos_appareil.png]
Capture écran HA infos appareil
  
</p>

Ainsi que la liste de ses "Capteurs" :

<p align="center">
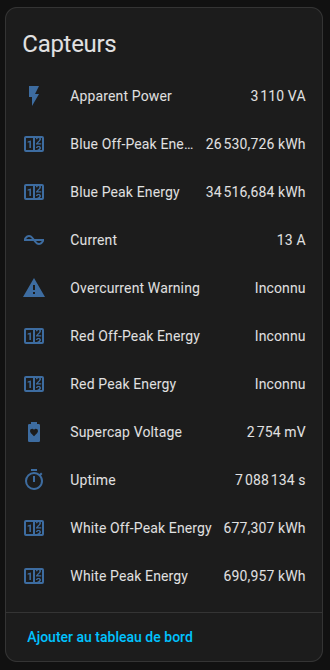
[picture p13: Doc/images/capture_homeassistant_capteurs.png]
Capture écran HA capteurs
  
</p>

On y trouve entre autres :
- **Courant** (IINST) — mesure instantanée
- **Index d'énergie** (BASE, HPHC, TEMPO, etc.) — *total increasing*. Ces index sont facilement utilisables dans le tableau de bord "Energie" (une fois associés à des prix du kWh pour chaque période tarifaire)
- **Puissance apparente** (PAPP) — mesure instantanée
- **Avertissement de surintensité** (ADPS) — alerte de surcharge
- **Tension supercondensateur** (VCAP) — mesure instantanée
- **Uptime** — temps de fonctionnement en secondes

## Format des trames TIC Linky

> Source : [Enedis-NOI-CPT_54E — Sorties de télé-information client des appareils de comptage Linky](../Doc/Enedis-MOP-CPT_002E.pdf), §5.3.6 et §6.

### Couche Liaison 

Le Linky émet des **trames** en continu. Chaque trame est délimitée par `STX` (`0x02`) en début et `ETX` (`0x03`) en fin, et est composée de plusieurs **groupes d'information** :

```
STX <groupe d'info> <groupe d'info> ... <groupe d'info> ETX
```

Un groupe d'information porte une étiquette, une donnée et un checksum :

```
<LF><étiquette><SEP><donnée><SEP><checksum><CR>
```

(`LF` = `0x0A`, `CR` = `0x0D` ; le caractère `<SEP>` dépend du mode — voir ci-dessous.)

Le checksum est calculé pour chaque groupe d'information sur la zone contrôlée allant du début de l'étiquette au délimiteur précédant le checksum :

```c
uint8_t checksum = (sum_of_bytes & 0x3F) + 0x20;
```

Le résultat est toujours un caractère ASCII imprimable (entre `0x20` et `0x5F`).

Les deux modes (**historique** et **standard**) partagent cette structure ; ils diffèrent par le caractère séparateur, le débit série, la présence d'un horodatage et la liste des étiquettes émises.

### Mode historique

> Cette section n'est applicable qu'à un compteur Linky monophasé.

| | Mode historique |
|-|-|
| Débit série | 1200 bauds, 7E1 |
| Séparateur `<SEP>` | `SP` (`0x20`) |
| Horodatage | Aucun |
| Zone contrôlée par le checksum | `<étiquette><SP><donnée>` (le second `SP` est exclu) |

Exemple (corps d'une trame, sans STX/ETX) :
```
IINST 003 :
BASE 012345678 '
PAPP 00690 +
ADPS 030 !
```

**Étiquettes supportées par le firmware** :

| Étiquette | Description | Unité |
|---|---|---|
| `IINST` | Courant instantané | A |
| `PAPP` | Puissance apparente | VA |
| `ADPS` | Avertissement de surintensité | A |
| `BASE` | Index énergie — contrat **BASE** | Wh |
| `HCHC`, `HCHP` | Index énergie — contrat **HP/HC** | Wh |
| `EJPHN`, `EJPHPM` | Index énergie — contrat **EJP** | Wh |
| `BBRHCJB`, `BBRHPJB`, `BBRHCJW`, `BBRHPJW`, `BBRHCJR`, `BBRHPJR` | Index énergie — contrat **Tempo** | Wh |

### Mode standard

> Cette section n'est applicable qu'à un compteur Linky monophasé.

| | Mode standard |
|-|-|
| Débit série | 9600 bauds, 7E1 |
| Séparateur `<SEP>` | `HT` (`0x09`) |
| Horodatage | Optionnel, intercalé entre l'étiquette et la donnée : `<LF><étiquette><HT><horodate><HT><donnée><HT><checksum><CR>` |
| Zone contrôlée par le checksum | Inclut le `HT` final (avant le checksum) |

> [!WARNING]
> Non supporté par le firmware actuel.

## Logiciel requis

- **ESP-IDF v5.4.1** ou supérieur
- **Bibliothèque HULP** (incluse en sous-module)

## Compilation et flashage

### 1. Cloner et initialiser

```bash
cd /chemin/vers/LinKey/Firmware
git submodule update --init --recursive
```

### 2. Configurer l'environnement ESP-IDF

```bash
source ~/esp/v5.4.1/esp-idf/export.sh
```

### 3. Configurer le projet

```bash
idf.py menuconfig
```

Naviguer dans **« Linkey Monitor Configuration »** et configurer :

#### Paramètres requis :
- **Device Name** : override optionnel du nom affiché dans Home Assistant. Si vide, le firmware utilise `Linkey_<suffixe_mac>`, par exemple `Linkey_8ebde0`.
- **Provisioning Proof of Possession** : code demandé par l'application Espressif

#### Paramètres optionnels :
- **Auto-discover MQTT broker with mDNS** : activé par défaut ; découvre Home Assistant via `_home-assistant._tcp.local` et utilise le port MQTT `1883`
- **MQTT Broker URI** : URI de repli si la découverte mDNS échoue (par défaut : `mqtt://homeassistant.local:1883`)
- **MQTT Username** : optionnel ; si vide, le firmware utilise `linkey_<6 derniers caractères de la MAC WiFi>`
- **MQTT Password** : si votre broker requiert une authentification
- **Use Static IP** : à activer pour une connexion initiale plus rapide
- **Enable debug logging** : logs verbeux et QR code de provisioning dans le moniteur série

### 4. Compiler

```bash
idf.py build
```

### 5. Flasher

```bash
idf.py -p /dev/ttyUSB0 flash monitor
```

### 6. Provisionner le WiFi

Au premier démarrage, si aucun identifiant WiFi n'est stocké :

1. Ouvrir l'application Espressif de provisioning.
2. Scanner le QR code affiché dans le moniteur série si les logs de debug sont activés, ou sélectionner manuellement le périphérique BLE `Linkey_XXXXXX`, puis entrer le *Proof of Possession* configuré dans `menuconfig`.
3. Saisir le SSID et le mot de passe WiFi manuellement (la recherche de réseaux par l'ESP32 est volontairement désactivée).
4. L'application doit terminer avec succès. Le firmware arrête ensuite le provisioning et attend à nouveau une tension suffisante avant de se connecter au WiFi.

Pour reprovisionner un appareil déjà configuré, maintenir BOOT/GPIO0 plus de 2 s pendant que l'appareil est dans un état actif. Les identifiants existants restent présents tant que l'application ne soumet pas de nouveaux identifiants.

## Tests

Les tests unitaires *host* couvrent la logique pure extraite des modules, notamment `voltage_state.c`, `fsm.c` et `tic_parser.c`. Le framework Unity est récupéré à la configuration via `FetchContent`.

### Exécuter localement

Pour exécuter les tests localement :

```bash
cd Firmware/test/host
cmake -B build
cmake --build build
ctest --test-dir build --output-on-failure
```

Temps d'exécution attendu : < 1 s pour les tests actuels.

### Intégration continue (CI)

Le workflow GitHub Actions `.github/workflows/ci.yml` lance à chaque *push* et *pull request* :

1. **`host-tests`** — `ubuntu-latest`, build CMake + Unity + ctest.
2. **`firmware-build`** — image Docker `espressif/idf:release-v5.4`, `idf.py build` complet pour valider que les refactorings ne cassent pas la compilation du firmware. La matrice couvre aussi une configuration avec `CONFIG_LINKEY_DEBUG_LOGS=y`, qui active notamment le QR code de provisioning.

### Ajouter un nouveau test

Tout fichier `*_state.c` / `*_logic.c` / `*_payload.c` dans `Firmware/main/` sans `#include` ESP-IDF est testable ici. Ajouter un `test_<nom>.c` dans `Firmware/test/host/`, puis une paire `add_executable` / `add_test` dans son `CMakeLists.txt`.

### Tests qui nécessiteraient des mocks

L'approche actuelle teste uniquement la logique pure extraite. Étendre la couverture aux modules suivants imposerait de simuler tout ou partie de l'API ESP-IDF — soit avec des stubs écrits à la main (header `esp_log.h` neutralisé, etc.), soit avec un générateur comme **CMock**.

## Références

- [Bibliothèque HULP](https://github.com/boarchuz/HULP)
- [Documentation ULP ESP32](https://docs.espressif.com/projects/esp-idf/en/latest/esp32/api-reference/system/ulp.html)
- [Documentation TIC Linky](../Doc/Enedis-MOP-CPT_002E.pdf) — spécification TIC Linky (incluse dans `Doc/`)
- [Gestion d'énergie ESP32](https://docs.espressif.com/projects/esp-idf/en/latest/esp32/api-reference/system/power_management.html)
- [Découverte d'instance Home Assistant](https://developers.home-assistant.io/docs/api/instance_discovery/)
- [Découverte MQTT HA](https://www.home-assistant.io/integrations/mqtt/#mqtt-discovery)

## Licence

Le code du firmware (`Firmware/main/`) est distribué sous **licence MIT**. Voir [`Firmware/LICENSE`](LICENSE) pour le texte complet.

> [!NOTE]
> Le matériel (sources KiCad, Gerbers, modèles 3D dans `PCB/`) est distribué sous une licence distincte — **CERN-OHL-W-2.0** — voir [`LICENSE`](../LICENSE) à la racine du dépôt.

### Dépendances tierces

- **HULP** (`Firmware/HULP/`, sous-module Git) — [MIT](HULP/LICENSE), © 2019 Matt
- **ESP-IDF** — [Apache 2.0](https://github.com/espressif/esp-idf/blob/master/LICENSE)
- **espressif/qrcode** (`Firmware/main/idf_component.yml`) — composant ESP-IDF utilisé uniquement par les builds avec logs de debug pour afficher le QR code de provisioning
- **espressif/mdns** (`Firmware/main/idf_component.yml`) — composant ESP-IDF utilisé pour découvrir l'instance Home Assistant sur le réseau local

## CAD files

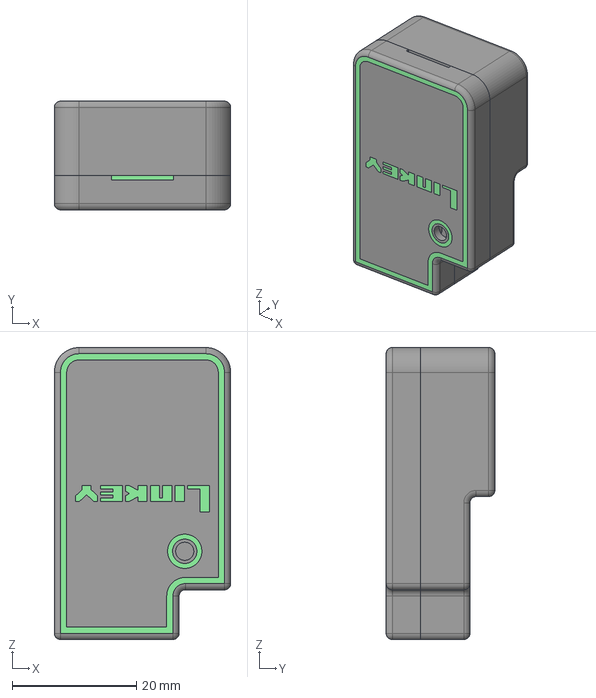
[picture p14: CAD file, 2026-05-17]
CAO/Linkey-boitier-v2.step
28.4 x 17.5 x 47.0 mm

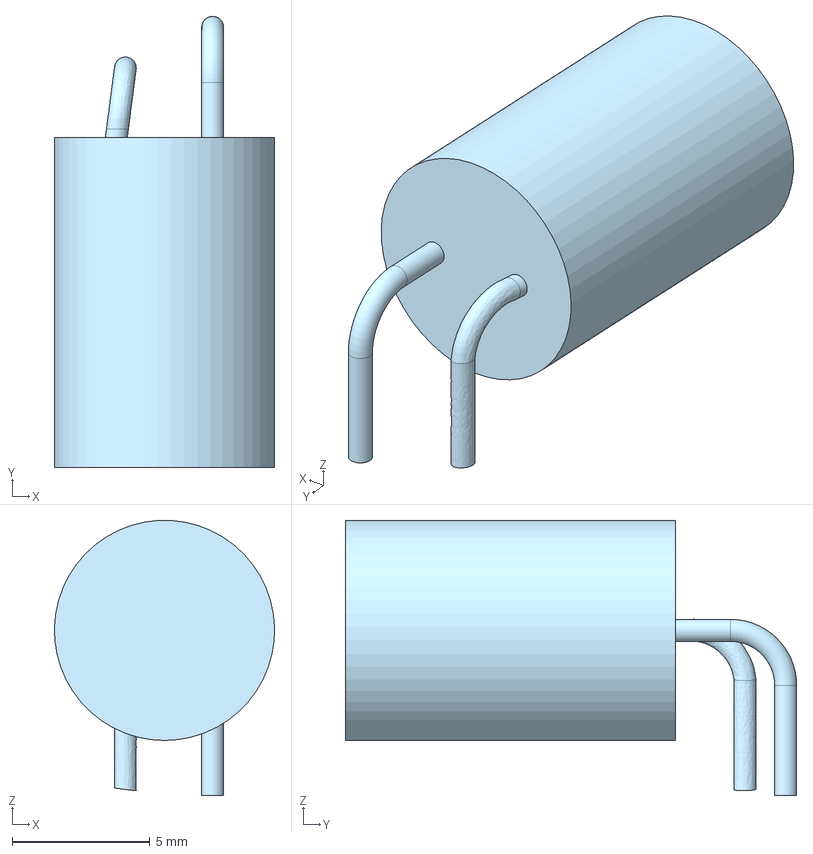
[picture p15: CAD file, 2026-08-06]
PCB/MCAD files/3D step files/Capacitor_THT-CP_Radial_D8.0mm_P3.50mm_special_position - Capacitor_THT-CP_Radial_D8.0mm_P3.50mm_special_position.step
8.00 x 16.4 x 9.99 mm

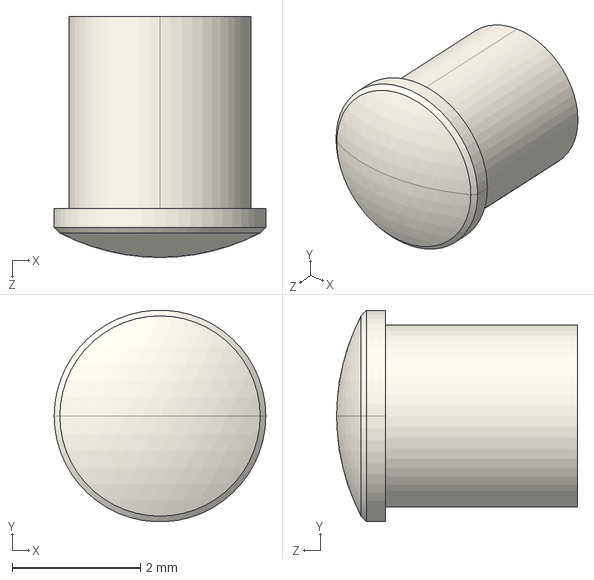
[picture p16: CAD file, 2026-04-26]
PCB/MCAD files/3D step files/PLP2-3MM-D.stp
3.30 x 3.30 x 3.76 mm

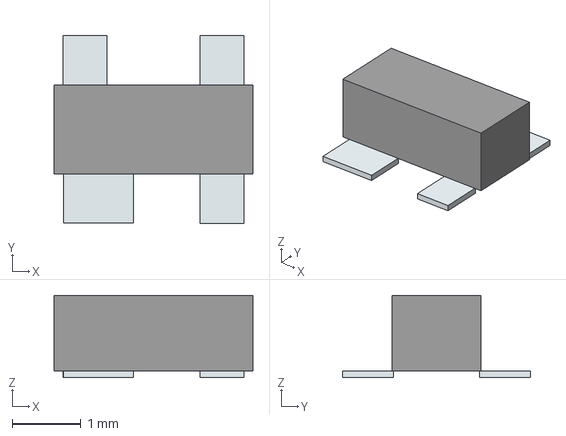
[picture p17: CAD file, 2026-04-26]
PCB/MCAD files/3D step files/BAS_4002A_RPP_E6327.stp
2.90 x 2.74 x 1.20 mm
Pins

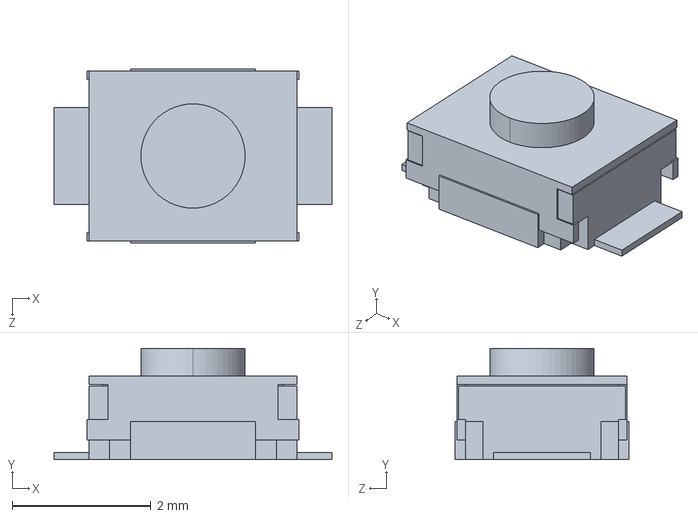
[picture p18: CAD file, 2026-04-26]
PCB/MCAD files/3D step files/B3U-1000P.stp
4.00 x 1.60 x 2.50 mm

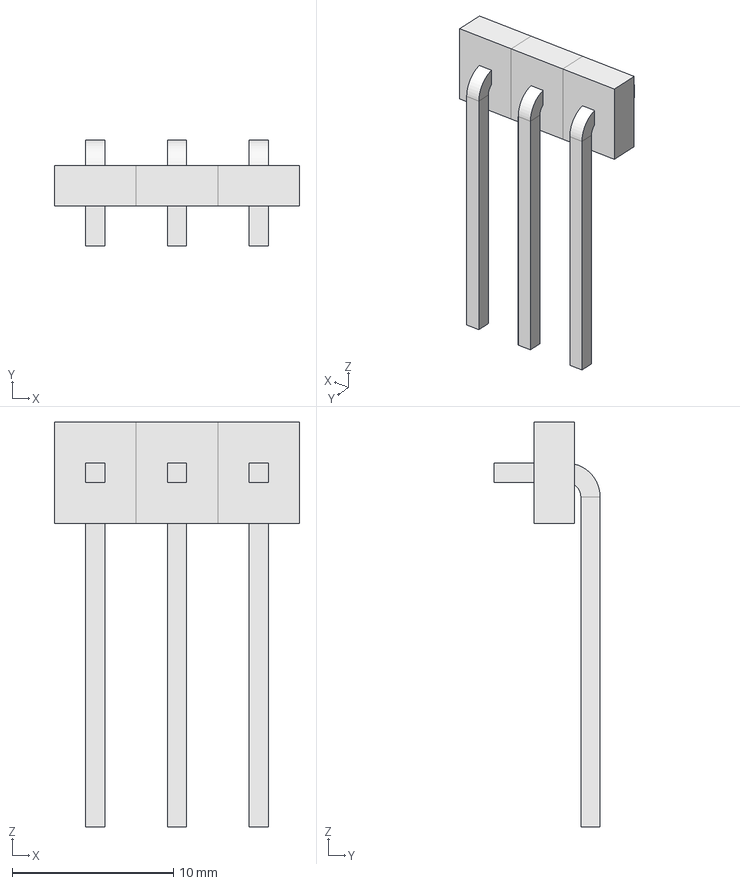
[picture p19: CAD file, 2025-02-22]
PCB/MCAD files/3D step files/Conn_01x03.step
15.2 x 6.60 x 25.1 mm

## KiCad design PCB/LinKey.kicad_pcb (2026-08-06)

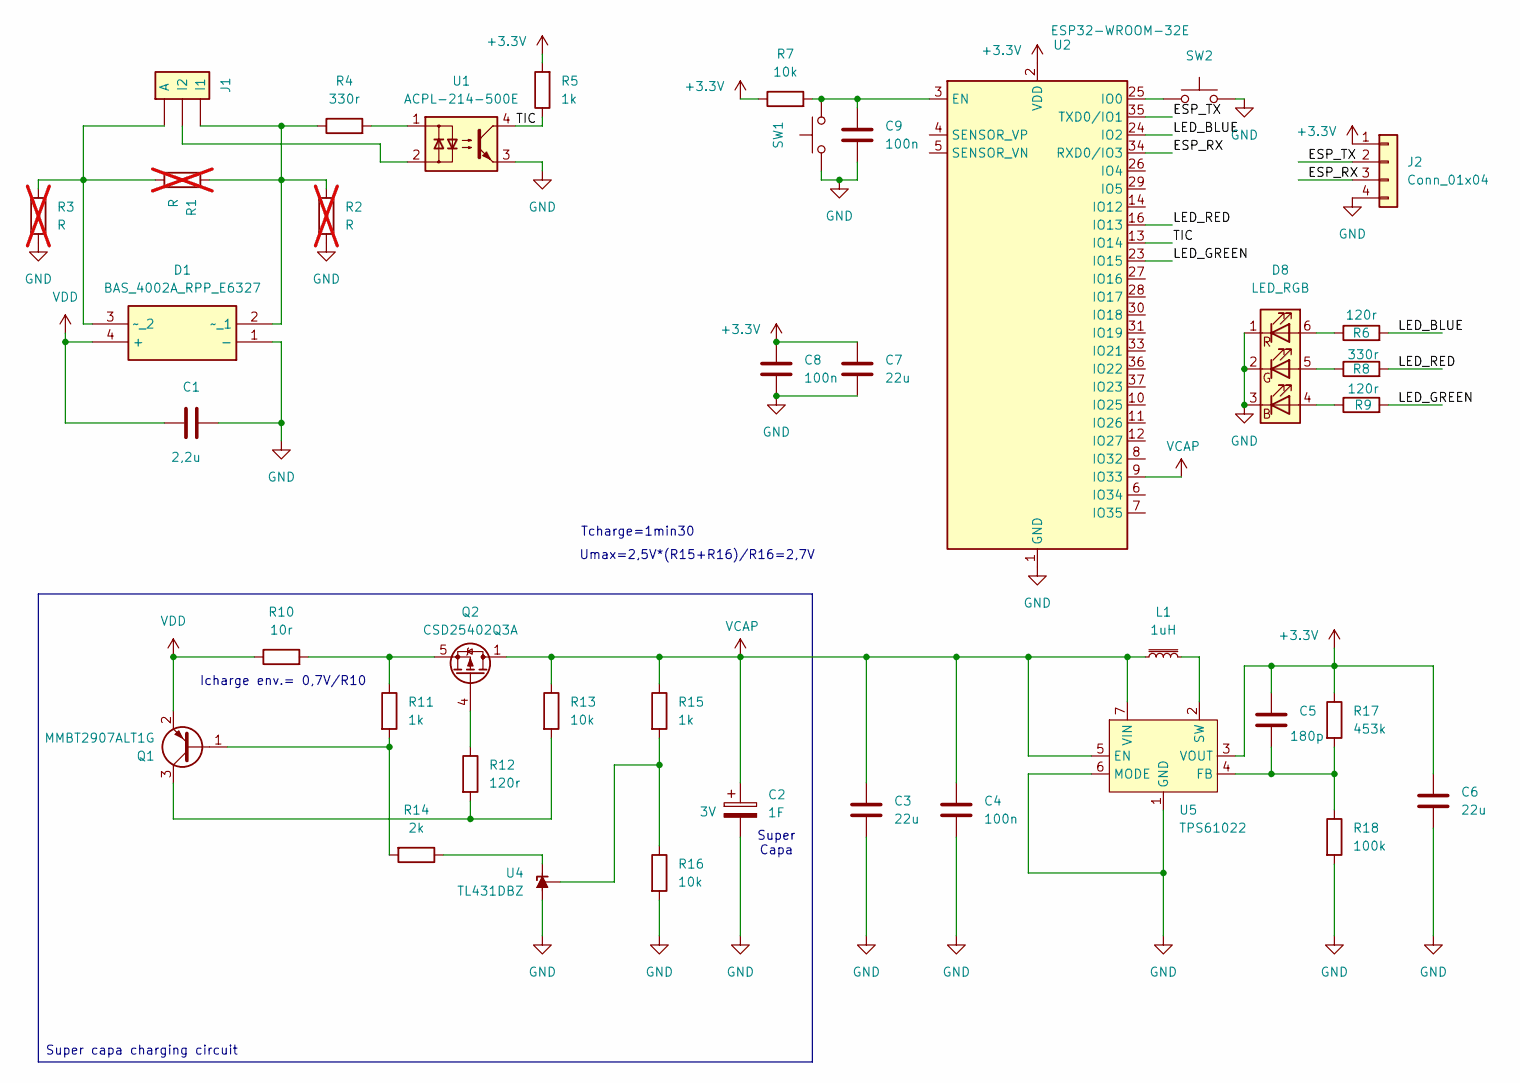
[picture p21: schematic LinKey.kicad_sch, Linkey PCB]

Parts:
C1: 2,2u; C_0805_2012Metric_Pad1.18x1.45mm_HandSolder; Voltage 16V; Manufacturer_Part_Number CL21B225KOFNNNF
C2: 1F; CP_Radial_D8.0mm_P3.50mm; Voltage 3V; Manufacturer_Part_Number SCCR12E105SRB
C3, C6, C7: 22u; C_1206_3216Metric_Pad1.33x1.80mm_HandSolder; Voltage 10V; Manufacturer_Part_Number CL31B226KPHNNNE
C4, C8, C9: 100n; C_0603_1608Metric_Pad1.08x0.95mm_HandSolder; Voltage 50V; Manufacturer_Part_Number CC0603JRX7R9BB104
C5: 180p; C_0603_1608Metric_Pad1.08x0.95mm_HandSolder; Voltage 50V; Manufacturer_Part_Number CC603KRX7R9BB181
D1: BAS_4002A_RPP_E6327; BAS4002ARPPE6327; Manufacturer_Part_Number BAS 4002A RPP E6327
D8: LED_RGB; LED_RGB_5050-6; Manufacturer_Part_Number BL-HBXJXGX32L
J1: Conn_01x03_TIC; Manufacturer_Part_Number HPM-03-04-T-S
J2: Conn_01x04; PinHeader_1x04_P2.54mm_Vertical
L1: 1uH; L_Coilcraft_XAL5030-XXX; Manufacturer_Part_Number XEL5030-102MEC
Q1: MMBT2907ALT1G; SOT-23_Handsoldering; Voltage 60V; Manufacturer_Part_Number MMBT2907ALT1G
Q2: CSD25402Q3A; VSON-8_3.3x3.3mm_P0.65mm_NexFET; Voltage 20V; Manufacturer_Part_Number CSD25402Q3A
R1, R2, R3: R; R_0603_1608Metric_Pad0.98x0.95mm_HandSolder; not fitted
R4, R8: 330r; R_0603_1608Metric_Pad0.98x0.95mm_HandSolder; Voltage 75V; Manufacturer_Part_Number CRCW0603330RFKEAC
R5, R11, R15: 1k; R_0603_1608Metric_Pad0.98x0.95mm_HandSolder; Voltage 75V; Manufacturer_Part_Number CRCW06031K00FKEAC
R6, R9, R12: 120r; R_0603_1608Metric_Pad0.98x0.95mm_HandSolder; Voltage 75V; Manufacturer_Part_Number CRCW0603120RFKEAC
R7, R13, R16: 10k; R_0603_1608Metric_Pad0.98x0.95mm_HandSolder; Voltage 75V; Manufacturer_Part_Number CRCW060310K0FKECC
R10: 10r; R_0805_2012Metric_Pad1.20x1.40mm_HandSolder; Voltage 150V; Manufacturer_Part_Number CRCW080510R0FKEA
R14: 2k; R_0603_1608Metric_Pad0.98x0.95mm_HandSolder; Voltage 75V; Manufacturer_Part_Number CRCW06032K00FKEAC
R17: 453k; R_0603_1608Metric_Pad0.98x0.95mm_HandSolder; Manufacturer_Part_Number CRCW0603453KFKEAC
R18: 100k; R_0603_1608Metric_Pad0.98x0.95mm_HandSolder; Voltage 75V; Manufacturer_Part_Number CRCW0603100KFKEAC
SW1, SW2: B3U-1000P; Manufacturer_Part_Number B3U-1000P
U1: ACPL-214-500E; SOP-4_4.4x2.6mm_P1.27mm; Manufacturer_Part_Number ACPL-214-500E
U2: ESP32-WROOM-32E; Manufacturer_Part_Number ESP32-WROOM-32E-N8
U4: TL431DBZ; SOT-23; Manufacturer_Part_Number TL431AIDBZR
U5: TPS61022; Texas_RWU0007A_VQFN-7_2x2mm_P0.5mm; Manufacturer_Part_Number TPS61022RWUT

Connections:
+3.3V: C5.1, C6.1, C7.1, C8.1, J2.1, R5.2, R7.1, R17.1, U2.2 (VDD), U5.3 (VOUT)
/ESP_RX: J2.3, U2.34 (RXD0/IO3)
/ESP_TX: J2.2, U2.35 (TXD0/IO1)
/LED_BLUE: R6.2, U2.24 (IO2)
/LED_GREEN: R9.2, U2.23 (IO15)
/LED_RED: R8.2, U2.16 (IO13)
/TIC: R5.1, U1.4, U2.13 (IO14)
GND: C1.2, C2.2, C3.2, C4.2, C6.2, C7.2, C8.2, C9.2, D1.1 (-), D8.1 (RK), D8.2 (GK), D8.3 (BK), J2.4, R2.2, R3.2, R16.2, R18.2, SW1.1, SW2.2, U1.3, U2.1 (GND), U2.15 (GND), U2.38 (GND), U2.39 (GND), U4.3 (A), U5.1 (GND), U5.6 (MODE)
unnamed: D1.2 (~_1), J1.3 (I1), R1.1, R2.1, R4.1
unnamed: D1.3 (~_2), J1.1 (A), R1.2, R3.1
unnamed: D8.4 (BA), R9.1
unnamed: D8.5 (GA), R8.1
unnamed: D8.6 (RA), R6.1
unnamed: J1.2 (I2), U1.2
unnamed: Q1.1 (B), R11.2, R14.2
unnamed: Q1.3 (C), R12.2, R13.2
unnamed: Q2.4 (G), R12.1
unnamed: Q2.5 (S), R10.2, R11.1
unnamed: R4.2, U1.1
unnamed: C9.1, R7.2, SW1.2, U2.3 (EN)
unnamed: SW2.1, U2.25 (IO0)
unnamed: R14.1, U4.1 (K)
unnamed: R15.2, R16.1, U4.2 (REF)
unnamed: C5.2, R17.2, R18.1, U5.4 (FB)
unnamed: L1.2, U5.2 (SW)
VCAP: C2.1, C3.1, C4.1, L1.1, Q2.1 (D), Q2.2 (D), Q2.3 (D), R13.1, R15.1, U2.9 (IO33), U5.5 (EN), U5.7 (VIN)
VDD: C1.1, D1.4 (+), Q1.2 (E), R10.1

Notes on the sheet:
Icharge env.= 0,7V/R10
Tcharge=1min30
Super Capa
Umax=2,5V*(R15+R16)/R16=2,7V
Super capa charging circuit

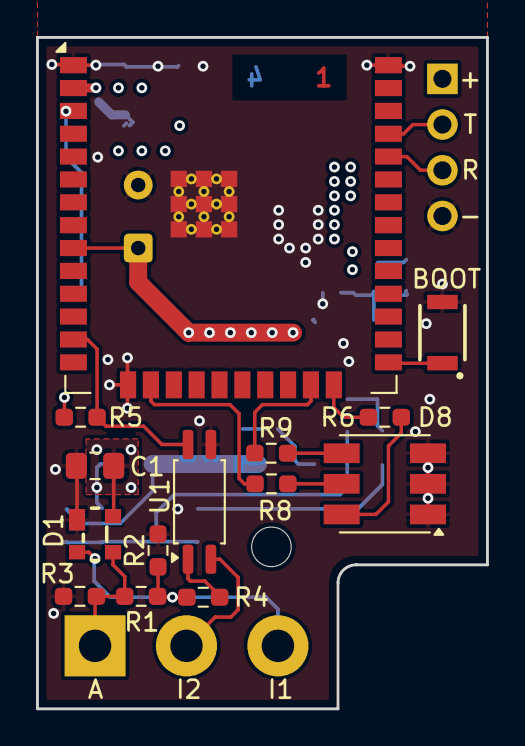
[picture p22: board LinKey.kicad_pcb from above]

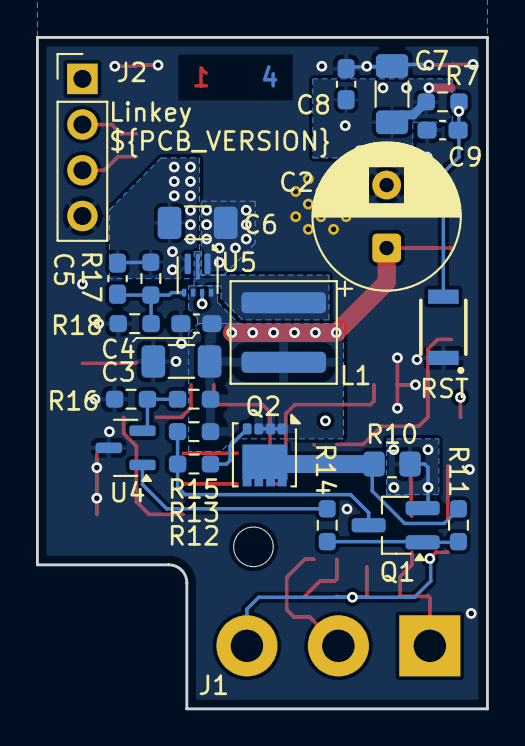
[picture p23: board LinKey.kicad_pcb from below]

Board: 4 copper layers, 25.0 x 37.3 mm, 40 parts (26 on the bottom side), 27 nets.

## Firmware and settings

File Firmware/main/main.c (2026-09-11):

#include <stdio.h>
#include <string.h>
#include "freertos/FreeRTOS.h"
#include "freertos/task.h"
#include "freertos/event_groups.h"
#include "esp_wifi.h"
#include "esp_event.h"
#include "esp_log.h"
#include "esp_pm.h"
#include "nvs_flash.h"
#include "driver/gpio.h"
#include "esp_timer.h"
#include "types.h"
#include "fsm.h"
#include "ulp_linky.h"
#include "voltage_manager.h"
#include "wifi_manager.h"
#include "mqtt_manager.h"
#include "provisioning_manager.h"
#include "debug.h"
#include "tic_types.h"

static const char *TAG = "LINKY_MAIN";

// RGB LED pin definitions
#define BOOT_BUTTON_PIN     GPIO_NUM_0
#define RGB_LED_RED_PIN     GPIO_NUM_13
#define RGB_LED_GREEN_PIN   GPIO_NUM_15
#define RGB_LED_BLUE_PIN    GPIO_NUM_2

// RGB Color macros - define colors as (R, G, B) where each is 0 or 1
#define RGB_COLOR(r, g, b)  ((r) | ((g) << 1) | ((b) << 2))
#define RGB_OFF             RGB_COLOR(0, 0, 0)
#define RGB_RED             RGB_COLOR(1, 0, 0)
#define RGB_GREEN           RGB_COLOR(0, 1, 0)
#define RGB_BLUE            RGB_COLOR(0, 0, 1)
#define RGB_YELLOW          RGB_COLOR(1, 1, 0)
#define RGB_CYAN            RGB_COLOR(0, 1, 1)
#define RGB_MAGENTA         RGB_COLOR(1, 0, 1)
#define RGB_WHITE           RGB_COLOR(1, 1, 1)

// State LED color configuration (easily customizable)
#define LED_COLOR_WAIT_VOLTAGE  RGB_RED
#define LED_COLOR_BLE_PROVISION RGB_WHITE
#define LED_COLOR_WIFI_CONNECT     RGB_BLUE
#define LED_COLOR_MQTT_CONNECT     RGB_MAGENTA
#define LED_COLOR_WAIT_ULP_DATA      RGB_YELLOW
#define LED_COLOR_PUBLISH_DATA       RGB_GREEN

// Timeouts (milliseconds)
#define WIFI_CONNECT_TIMEOUT_MS 6000    // WiFi connection timeout
#define MQTT_CONNECT_TIMEOUT_MS 1000    // MQTT connection timeout
#define BOOT_BUTTON_LONG_PRESS_MS 2000  // Hold BOOT/GPIO0 to reprovision
// Timeout waiting for ULP data: frame-level reception needs at least 2 frame periods
// (partial frame + first complete frame) before valid data is available
#if defined(CONFIG_LINKEY_TARIFF_TEMPO)
#define ULP_DATA_TIMEOUT_MS     5000
#elif defined(CONFIG_LINKEY_TARIFF_EJP)
#define ULP_DATA_TIMEOUT_MS     4000
#elif defined(CONFIG_LINKEY_TARIFF_HPHC)
#define ULP_DATA_TIMEOUT_MS     3500
#else
#define ULP_DATA_TIMEOUT_MS     3000
#endif
#define POLL_INTERVAL_MS        100     // Polling interval in connect/wait loops

static app_state_t current_state = STATE_WAIT_VOLTAGE;

// State LED colors lookup table
static const uint8_t state_colors[] = {
    LED_COLOR_WAIT_VOLTAGE,
    LED_COLOR_BLE_PROVISION,
    LED_COLOR_WIFI_CONNECT,
    LED_COLOR_MQTT_CONNECT,
    LED_COLOR_WAIT_ULP_DATA,
    LED_COLOR_PUBLISH_DATA
};

// WiFi state (owned by main, passed to wifi_manager)
static wifi_state_t wifi_state = {0};

// MQTT state (owned by main, passed to mqtt_manager)
static mqtt_state_t mqtt_state = {0};

// ULP initialization flag (one-time init)
static bool ulp_initialized = false;

// Task handle for ULP wake notification
static TaskHandle_t main_task_handle;
static TaskHandle_t ble_provision_led_task_handle = NULL;
static volatile bool ble_provision_led_blinking = false;
static volatile bool manual_provisioning_requested = false;

// ULP wake ISR: notify main task when a new frame is received
static void IRAM_ATTR ulp_isr(void *arg)
{
    BaseType_t woken = pdFALSE;
    vTaskNotifyGiveFromISR(*(TaskHandle_t *)arg, &woken);
    portYIELD_FROM_ISR(woken);
}

static bool boot_button_force_allowed(app_state_t state);

static void rgb_led_init(void)
{
    gpio_config_t io_conf = {
        .pin_bit_mask = (1ULL << RGB_LED_RED_PIN) | (1ULL << RGB_LED_GREEN_PIN) | (1ULL << RGB_LED_BLUE_PIN),
        .mode = GPIO_MODE_OUTPUT,
        .pull_up_en = GPIO_PULLUP_DISABLE,
        .pull_down_en = GPIO_PULLDOWN_DISABLE,
        .intr_type = GPIO_INTR_DISABLE,
    };
    ESP_ERROR_CHECK(gpio_config(&io_conf));

    // Turn off all LEDs initially (assuming active-high LEDs)
    gpio_set_level(RGB_LED_RED_PIN, 0);
    gpio_set_level(RGB_LED_GREEN_PIN, 0);
    gpio_set_level(RGB_LED_BLUE_PIN, 0);

    DEBUG_LOG(TAG, "RGB LEDs initialized (R:%d, G:%d, B:%d)", RGB_LED_RED_PIN, RGB_LED_GREEN_PIN, RGB_LED_BLUE_PIN);
}

static void boot_button_init(void)
{
    gpio_config_t io_conf = {
        .pin_bit_mask = (1ULL << BOOT_BUTTON_PIN),
        .mode = GPIO_MODE_INPUT,
        .pull_up_en = GPIO_PULLUP_ENABLE,
        .pull_down_en = GPIO_PULLDOWN_DISABLE,
        .intr_type = GPIO_INTR_DISABLE,
    };
    ESP_ERROR_CHECK(gpio_config(&io_conf));
    DEBUG_LOG(TAG, "BOOT button initialized (GPIO%d)", BOOT_BUTTON_PIN);
}

static bool boot_button_force_allowed(app_state_t state)
{
    return state != STATE_WAIT_VOLTAGE
        && state != STATE_BLE_PROVISION;
}

// Set LED to a color (from RGB_COLOR macro)
static void rgb_led_set(uint8_t color)
{
    gpio_set_level(RGB_LED_RED_PIN,   (color >> 0) & 1);
    gpio_set_level(RGB_LED_GREEN_PIN, (color >> 1) & 1);
    gpio_set_level(RGB_LED_BLUE_PIN,  (color >> 2) & 1);
}

// Blink LED with color for specified duration, then turn off
static void rgb_led_blink(uint8_t color, int duration_ms)
{
    rgb_led_set(color);
    vTaskDelay(pdMS_TO_TICKS(duration_ms));
    rgb_led_set(RGB_OFF);
}

static void ble_provision_led_task(void *arg)
{
    (void)arg;

    while (ble_provision_led_blinking) {
        rgb_led_blink(LED_COLOR_BLE_PROVISION, 10);
        vTaskDelay(pdMS_TO_TICKS(1990));
    }

    rgb_led_set(RGB_OFF);
    ble_provision_led_task_handle = NULL;
    vTaskDelete(NULL);
}

static void ble_provision_led_start(void)
{
    if (ble_provision_led_task_handle) {
        return;
    }

    ble_provision_led_blinking = true;
    ESP_ERROR_CHECK(xTaskCreate(ble_provision_led_task, "ble_prov_led", 2048,
                                NULL, 1, &ble_provision_led_task_handle) == pdPASS
        ? ESP_OK
        : ESP_ERR_NO_MEM);
}

static void ble_provision_led_stop(void)
{
    ble_provision_led_blinking = false;
}

// Stop WiFi and MQTT (WiFi first to cut radio power immediately)
static void stop_all_connections(void)
{
    wifi_stop(&wifi_state);
    mqtt_stop(&mqtt_state);
}

// Wait for ULP data to be received (with voltage checks)
static conn_result_t ulp_wait_data(void)
{
    linky_data_t data;
    TickType_t deadline = xTaskGetTickCount() + pdMS_TO_TICKS(ULP_DATA_TIMEOUT_MS);

    while (xTaskGetTickCount() < deadline) {
        // Block until ULP notification or periodic check interval
        ulTaskNotifyTake(pdTRUE, pdMS_TO_TICKS(POLL_INTERVAL_MS));

        if (voltage_is_low_dynamic(VOLTAGE_FALLBACK_MIN_MV)) {
            return CONN_VOLTAGE_LOW;
        }
        if (!wifi_is_connected() || !mqtt_is_connected(&mqtt_state)) {
            return CONN_WIFI_LOST;
        }

        get_linky_data(&data);
        if (data.valid_flags != 0) {
            DEBUG_LOG(TAG, "ULP data received (flags: 0x%04x)", data.valid_flags);
            return CONN_OK;
        }
    }

    DEBUG_LOGW(TAG, "ULP data reception timeout");
    return CONN_FAILED;
}

// Forward declarations for state handlers
static app_state_t handle_state_init(void);
static app_state_t handle_state_wait_voltage(void);
static app_state_t handle_state_ble_provision(void);
static app_state_t handle_state_wifi_connect(void);
static app_state_t handle_state_mqtt_connect(void);
static app_state_t handle_state_wait_ulp_data(void);
static app_state_t handle_state_publish_data(void);

// Initialize LED, ADC, pm_config
static app_state_t handle_state_init(void)
{
    // Initialize NVS (used for WiFi)
    esp_err_t ret = nvs_flash_init();
    if (ret == ESP_ERR_NVS_NO_FREE_PAGES || ret == ESP_ERR_NVS_NEW_VERSION_FOUND) {
        ESP_ERROR_CHECK(nvs_flash_erase());
        ret = nvs_flash_init();
    }
    ESP_ERROR_CHECK(ret);

    // Initialize RGB LEDs
    rgb_led_init();
    boot_button_init();

    // Initialize voltage monitoring
    voltage_init();

    // Configure automatic power management for light sleep
    esp_pm_config_t pm_config = {
        .max_freq_mhz = 160,
        .min_freq_mhz = 40,
        .light_sleep_enable = true
    };
    ESP_ERROR_CHECK(esp_pm_configure(&pm_config));
    DEBUG_LOG(TAG, "Power management configured: auto light sleep enabled");

    return STATE_WAIT_VOLTAGE;
}

// STATE_WAIT_VOLTAGE: Wait for voltage >= 2.5V
static app_state_t handle_state_wait_voltage(void)
{
    int voltage_mv = voltage_read_mv();
    DEBUG_LOG(TAG, "Supercap voltage: %d mV", voltage_mv);

    if (voltage_mv >= VOLTAGE_START_MV) {
        if (!wifi_state.initialized) {
            DEBUG_LOG(TAG, "Initializing WiFi...");
            wifi_init(&wifi_state);
        }

        if (!wifi_has_config()) {
            DEBUG_LOG(TAG, "Voltage sufficient but WiFi is not provisioned");
            return STATE_BLE_PROVISION;
        }

        DEBUG_LOG(TAG, "Voltage sufficient - proceeding to WiFi connect");
        return STATE_WIFI_CONNECT;
    }

    return STATE_WAIT_VOLTAGE;
}

// STATE_BLE_PROVISION: Provision WiFi credentials over BLE
static app_state_t handle_state_ble_provision(void)
{
    if (!wifi_state.initialized) {
        DEBUG_LOG(TAG, "Initializing WiFi for provisioning...");
        wifi_init(&wifi_state);
    }

    DEBUG_LOG(TAG, "Starting BLE WiFi provisioning...");
    ble_provision_led_start();
    conn_result_t result = provisioning_start_ble(VOLTAGE_FALLBACK_MIN_MV,
                                                 POLL_INTERVAL_MS);
    ble_provision_led_stop();
    if (result == CONN_OK) {
        DEBUG_LOG(TAG, "WiFi credentials stored - returning to WAIT_VOLTAGE");
        stop_all_connections();
        return STATE_WAIT_VOLTAGE;
    }
    if (result == CONN_VOLTAGE_LOW) {
        DEBUG_LOGW(TAG, "Voltage too low - returning to WAIT_VOLTAGE");
        stop_all_connections();
        return STATE_WAIT_VOLTAGE;
    }

    if (wifi_has_config()) {
        DEBUG_LOGW(TAG, "BLE provisioning failed - keeping previous credentials");
        stop_all_connections();
        return STATE_WAIT_VOLTAGE;
    }

    DEBUG_LOGW(TAG, "BLE provisioning failed - retrying");
    stop_all_connections();
    return STATE_BLE_PROVISION;
}

static void poll_boot_button_for_reprovision(void)
{
    static bool was_pressed = false;
    static bool must_release = false;
    static uint32_t pressed_ms = 0;
    static TickType_t last_poll_tick = 0;
    TickType_t now = xTaskGetTickCount();
    uint32_t elapsed_ms = (last_poll_tick == 0)
        ? 0
        : pdTICKS_TO_MS(now - last_poll_tick);
    bool pressed = gpio_get_level(BOOT_BUTTON_PIN) == 0;

    last_poll_tick = now;

    if (!boot_button_force_allowed(current_state)) {
        was_pressed = false;
        must_release = false;
        pressed_ms = 0;
        return;
    }

    if (must_release) {
        // Wait for a release before allowing another long-press request
        if (!pressed) {
            must_release = false;
            pressed_ms = 0;
        }
        return;
    } else if (pressed) {
        // Start timing on a fresh press
        if (!was_pressed) {
            pressed_ms = 0;
        } else {
            pressed_ms += elapsed_ms;
        }
        // If the button has been pressed long enough:
        //  - request manual provisioning
        //  - and block further requests until the button is released
        if (pressed_ms >= BOOT_BUTTON_LONG_PRESS_MS) {
            manual_provisioning_requested = true;
            must_release = true;
        }
    }

    was_pressed = pressed;
}

static void handle_manual_provisioning_request(void)
{
    poll_boot_button_for_reprovision();

    if (manual_provisioning_requested) {
        manual_provisioning_requested = false;
        DEBUG_LOGW(TAG, "BOOT button long pressed - requesting WiFi provisioning");
        stop_all_connections();
        current_state = STATE_BLE_PROVISION;
    }
}

// STATE_WIFI_CONNECT: Initialize WiFi (once) and connect
static app_state_t handle_state_wifi_connect(void)
{
    // One-time WiFi initialization
    if (!wifi_state.initialized) {
        DEBUG_LOG(TAG, "Initializing WiFi...");
        wifi_init(&wifi_state);
    }

    // Restart WiFi if it was stopped
    if (!wifi_state.started) {
        DEBUG_LOG(TAG, "Restarting WiFi...");
        wifi_start(&wifi_state);
    }

    DEBUG_LOG(TAG, "Connecting to WiFi...");

    conn_result_t result = wifi_connect(&wifi_state, voltage_is_low,
                                        VOLTAGE_FALLBACK_MIN_MV,
                                        WIFI_CONNECT_TIMEOUT_MS, POLL_INTERVAL_MS);
    if (result == CONN_VOLTAGE_LOW) {
        DEBUG_LOGW(TAG, "Voltage too low - stopping WiFi and returning to WAIT_VOLTAGE");
        stop_all_connections();
    } else if (result == CONN_OK) {
        DEBUG_LOG(TAG, "WiFi connected - proceeding to MQTT init");
    } else {
        DEBUG_LOG(TAG, "WiFi connection failed - retrying...");
    }
    return fsm_after_wifi_connect(result);
}

// STATE_MQTT_CONNECT: Initialize MQTT (once) and connect
static app_state_t handle_state_mqtt_connect(void)
{
    // One-time MQTT initialization
    if (!mqtt_state.initialized) {
        DEBUG_LOG(TAG, "Initializing MQTT...");
        mqtt_init(&mqtt_state);
    }

    DEBUG_LOG(TAG, "Connecting to MQTT...");
    // Connect MQTT with voltage checks (dynamic threshold) and WiFi checks (exit early if WiFi lost)
    conn_result_t result = mqtt_connect(&mqtt_state, voltage_is_low_dynamic,
                                        VOLTAGE_FALLBACK_MIN_MV, wifi_is_connected,
                                        MQTT_CONNECT_TIMEOUT_MS, POLL_INTERVAL_MS);
    if (result == CONN_VOLTAGE_LOW || result == CONN_WIFI_LOST) {
        DEBUG_LOGW(TAG, "%s", result == CONN_VOLTAGE_LOW
            ? "Voltage too low - stopping WiFi and returning to WAIT_VOLTAGE"
            : "WiFi lost during MQTT connect - returning to WIFI_CONNECT");
        stop_all_connections();
    } else if (result == CONN_OK) {
        DEBUG_LOG(TAG, "MQTT connected - proceeding to ULP_WAIT_DATA");
    } else {
        DEBUG_LOG(TAG, "MQTT not available - retrying...");
    }
    return fsm_after_mqtt_connect(result);
}

// STATE_WAIT_ULP_DATA: Initialize ULP (once) and wait for data
static app_state_t handle_state_wait_ulp_data(void)
{
    // One-time ULP initialization + ISR registration
    if (!ulp_initialized) {
        DEBUG_LOG(TAG, "Initializing ULP...");
        main_task_handle = xTaskGetCurrentTaskHandle();
        hulp_ulp_isr_register(&ulp_isr, &main_task_handle);
        hulp_ulp_interrupt_en();
        init_ulp_linky();
        ulp_initialized = true;
    }

    DEBUG_LOG(TAG, "Waiting for ULP data...");

    conn_result_t result = ulp_wait_data();
    if (result == CONN_VOLTAGE_LOW || result == CONN_WIFI_LOST) {
        DEBUG_LOGW(TAG, "%s", result == CONN_VOLTAGE_LOW
            ? "Voltage too low - stopping WiFi and returning to WAIT_VOLTAGE"
            : "WiFi or MQTT lost during ULP wait - returning to WIFI_CONNECT");
        stop_all_connections();
    } else if (result == CONN_OK) {
        DEBUG_LOG(TAG, "ULP data confirmed - entering PUBLISH_DATA state");
    } else {
        DEBUG_LOG(TAG, "ULP data not received - waiting...");
    }
    return fsm_after_wait_ulp_data(result);
}

// STATE_PUBLISH_DATA: Normal operation - get data and publish
static app_state_t handle_state_publish_data(void)
{
    linky_data_t linky_data;
    bool data_valid = false;
    bool publish_ok = false;

    // Short-circuit guards preserve the original call ordering: each
    // downstream check is only evaluated when its precondition holds.
    bool v_low   = voltage_is_low_dynamic(VOLTAGE_FALLBACK_MIN_MV);
    bool wifi_ok = !v_low   && wifi_is_connected();
    bool mqtt_ok =  wifi_ok && mqtt_is_connected(&mqtt_state);

    if (mqtt_ok) {
        get_linky_data(&linky_data);
        linky_data.voltage_cap = voltage_read_mv();
        linky_data.uptime_s = (uint32_t)(esp_timer_get_time() / 1000000);
        data_valid = (linky_data.valid_flags != 0);
        if (data_valid) {
            DEBUG_LOG(TAG, "Linky data received (flags: 0x%04x, IINST: %u A)",
                    linky_data.valid_flags, linky_data.iinst);
            publish_ok = mqtt_publish_linky_data(&mqtt_state, &linky_data);
            
            // Handle debug frame request if flagged
            if (mqtt_state.debug_frame_requested) {
                char debug_frame[LINKY_MAX_FRAME_LEN + 1];
                int frame_len = get_last_tic_frame(debug_frame, sizeof(debug_frame));
                if (frame_len > 0) {
                    mqtt_publish_tic_frame_debug(&mqtt_state, debug_frame, frame_len);
                }
                mqtt_state.debug_frame_requested = false;
            }
            
            if (!publish_ok) {
                DEBUG_LOGW(TAG, "Publish failed - returning to MQTT_CONNECT");
            }
        } else {
            DEBUG_LOGW(TAG, "No ULP data received - returning to WAIT_ULP_DATA");
        }
    } else if (!wifi_ok && !v_low) {
        DEBUG_LOGW(TAG, "WiFi disconnected - returning to WIFI_CONNECT");
    } else if (wifi_ok) {
        DEBUG_LOGW(TAG, "MQTT disconnected - returning to MQTT_CONNECT");
    }

    if (v_low || !wifi_ok) stop_all_connections();
    return fsm_after_publish_data(v_low, wifi_ok, mqtt_ok, data_valid, publish_ok);
}

void app_main(void)
{
    DEBUG_LOG(TAG, "Starting FSM...");

    current_state = handle_state_init();
    app_state_t previous_state = current_state;

    while (1) {
        // Reset dynamic peak tracker on state transitions into dynamic states
        if (current_state != previous_state) {
            if (fsm_should_reset_peak_on_enter(current_state)) {
                voltage_reset_peak();
            }
            previous_state = current_state;
        }

        // STATE_WIFI_CONNECT uses the fixed floor (peak hasn't been built up yet);
        // every other connected state uses the dynamic drop-from-peak threshold.
        if (current_state != STATE_WAIT_VOLTAGE) {
            bool low = (current_state == STATE_WIFI_CONNECT)
                ? voltage_is_low(VOLTAGE_FALLBACK_MIN_MV)
                : voltage_is_low_dynamic(VOLTAGE_FALLBACK_MIN_MV);
            app_state_t next = fsm_voltage_watchdog_next(current_state, low);
            if (next != current_state) {
                stop_all_connections();
                current_state = next;
            }
        }

        handle_manual_provisioning_request();

        // Blink LED for current state (10ms)
        rgb_led_blink(state_colors[current_state], 10);

        // Handle current state
        switch (current_state) {
            case STATE_WAIT_VOLTAGE:
                current_state = handle_state_wait_voltage();
                break;
            case STATE_WIFI_CONNECT:
                current_state = handle_state_wifi_connect();
                break;
            case STATE_BLE_PROVISION:
                current_state = handle_state_ble_provision();
                break;
            case STATE_MQTT_CONNECT:
                current_state = handle_state_mqtt_connect();
                break;
            case STATE_WAIT_ULP_DATA:
                current_state = handle_state_wait_ulp_data();
                break;
            case STATE_PUBLISH_DATA:
                current_state = handle_state_publish_data();
                break;
        }

        // Wait for next event based on current state
        switch (current_state) {
            case STATE_PUBLISH_DATA:
                // Block until ULP signals a new frame is ready
                ulTaskNotifyTake(pdTRUE, pdMS_TO_TICKS(ULP_DATA_TIMEOUT_MS));
                break;
            default:
                vTaskDelay(pdMS_TO_TICKS(1000));
                break;
        }
    }
}

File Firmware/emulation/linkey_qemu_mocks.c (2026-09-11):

#include <string.h>
#include "esp_err.h"
#include "esp_eth.h"
#include "esp_eth_driver.h"
#include "esp_eth_netif_glue.h"
#include "esp_event.h"
#include "esp_log.h"
#include "esp_mac.h"
#include "esp_netif.h"
#include "esp_pm.h"
#include "esp_timer.h"
#include "driver/gpio.h"
#include "freertos/FreeRTOS.h"
#include "freertos/task.h"
#include "hulp.h"
#include "qemu_test_data.h"
#include "provisioning_manager.h"
#include "ulp_linky.h"
#include "voltage_manager.h"
#include "wifi_manager.h"

static const char *TAG = "LINKEY_QEMU";
static int qemu_voltage_mv = 2700;
static TaskHandle_t *qemu_main_task_handle;
static TaskHandle_t qemu_ulp_task_handle;
static bool qemu_next_buffer_is_1;
static esp_eth_handle_t qemu_eth_handle;
static esp_eth_netif_glue_handle_t qemu_eth_glue;
static bool qemu_eth_has_ip;
static const uint8_t qemu_wifi_sta_mac[6] = {0xaa, 0xbb, 0xcc, 0xdd, 0xee, 0xff};
#if defined(LINKEY_QEMU_MANUAL_PROVISION_TEST)
static bool qemu_boot_press_logged;
#endif

static const char *qemu_selected_frame(int *len)
{
#if defined(LINKEY_QEMU_TARIFF_OPTION_TEMPO)
    *len = TEST_TIC_FRAME_TEMPO_LEN;
    return TEST_TIC_FRAME_TEMPO;
#elif defined(LINKEY_QEMU_TARIFF_OPTION_EJP)
    *len = TEST_TIC_FRAME_EJP_LEN;
    return TEST_TIC_FRAME_EJP;
#elif defined(LINKEY_QEMU_TARIFF_OPTION_HPHC)
    *len = TEST_TIC_FRAME_HPHC_LEN;
    return TEST_TIC_FRAME_HPHC;
#else
    *len = TEST_TIC_FRAME_BASE_LEN;
    return TEST_TIC_FRAME_BASE;
#endif
}

static void qemu_write_frame_to_ulp_buffer(const char *frame, int len)
{
    ulp_var_t *buf = qemu_next_buffer_is_1 ? ulp_frame_buf_1 : ulp_frame_buf_0;
    const int capacity = 1 + (LINKY_MAX_FRAME_LEN / 2);

    if (len > LINKY_MAX_FRAME_LEN) {
        len = LINKY_MAX_FRAME_LEN;
    }

    memset(buf, 0, (size_t)capacity * sizeof(*buf));
    buf[0].val = (uint32_t)len;

    for (int i = 0; i < len; i++) {
        uint32_t shift = (uint32_t)((i % 2) * 8);
        buf[1 + (i / 2)].val |= ((uint32_t)(uint8_t)frame[i]) << shift;
    }

    ulp_active_buf.val = qemu_next_buffer_is_1 ? 1 : 0;
    qemu_next_buffer_is_1 = !qemu_next_buffer_is_1;
}

static void qemu_ulp_task(void *arg)
{
    (void)arg;

    while (1) {
        int frame_len = 0;
        const char *frame = qemu_selected_frame(&frame_len);

        qemu_write_frame_to_ulp_buffer(frame, frame_len);
        if (qemu_main_task_handle && *qemu_main_task_handle) {
            xTaskNotifyGive(*qemu_main_task_handle);
        }
        vTaskDelay(pdMS_TO_TICKS(5000));
    }
}

static void qemu_eth_event_handler(void *arg, esp_event_base_t event_base,
                                   int32_t event_id, void *event_data)
{
    (void)event_base;
    (void)event_data;
    wifi_state_t *state = (wifi_state_t *)arg;

    switch (event_id) {
    case ETHERNET_EVENT_CONNECTED:
        ESP_LOGI(TAG, "QEMU Ethernet link up");
        break;
    case ETHERNET_EVENT_DISCONNECTED:
        ESP_LOGW(TAG, "QEMU Ethernet link down");
        qemu_eth_has_ip = false;
        if (state && state->event_group) {
            xEventGroupClearBits(state->event_group, WIFI_CONNECTED_BIT);
            xEventGroupSetBits(state->event_group, WIFI_FAIL_BIT);
        }
        break;
    case ETHERNET_EVENT_START:
        ESP_LOGI(TAG, "QEMU Ethernet started");
        break;
    case ETHERNET_EVENT_STOP:
        ESP_LOGI(TAG, "QEMU Ethernet stopped");
        qemu_eth_has_ip = false;
        break;
    default:
        break;
    }
}

static void qemu_eth_got_ip_handler(void *arg, esp_event_base_t event_base,
                                    int32_t event_id, void *event_data)
{
    (void)event_base;
    (void)event_id;
    wifi_state_t *state = (wifi_state_t *)arg;
    ip_event_got_ip_t *event = (ip_event_got_ip_t *)event_data;

    qemu_eth_has_ip = true;
    ESP_LOGI(TAG, "QEMU Ethernet got IP: " IPSTR, IP2STR(&event->ip_info.ip));
    if (state && state->event_group) {
        xEventGroupClearBits(state->event_group, WIFI_FAIL_BIT);
        xEventGroupSetBits(state->event_group, WIFI_CONNECTED_BIT);
    }
}

static void qemu_check_esp(esp_err_t err)
{
    if (err != ESP_OK && err != ESP_ERR_INVALID_STATE) {
        ESP_ERROR_CHECK(err);
    }
}

esp_err_t __wrap_esp_pm_configure(const esp_pm_config_t *config)
{
    (void)config;
    ESP_LOGI(TAG, "Power management skipped for QEMU emulation");
    return ESP_OK;
}

int __real_gpio_get_level(gpio_num_t gpio_num);

int __wrap_gpio_get_level(gpio_num_t gpio_num)
{
    if (gpio_num == GPIO_NUM_0) {
#if defined(LINKEY_QEMU_MANUAL_PROVISION_TEST)
        int64_t now_ms = esp_timer_get_time() / 1000;
        bool pressed = now_ms >= 5000 && now_ms < 12000;
        if (pressed && !qemu_boot_press_logged) {
            ESP_LOGI(TAG, "QEMU manual BOOT/GPIO0 press active");
            qemu_boot_press_logged = true;
        }
        return pressed ? 0 : 1;
#else
        return 1;
#endif
    }
    return __real_gpio_get_level(gpio_num);
}

esp_err_t __real_esp_read_mac(uint8_t *mac, esp_mac_type_t type);

esp_err_t __wrap_esp_read_mac(uint8_t *mac, esp_mac_type_t type)
{
    if (!mac) {
        return ESP_ERR_INVALID_ARG;
    }
    if (type == ESP_MAC_WIFI_STA) {
        memcpy(mac, qemu_wifi_sta_mac, sizeof(qemu_wifi_sta_mac));
        return ESP_OK;
    }
    return __real_esp_read_mac(mac, type);
}

esp_err_t __wrap_hulp_ulp_isr_register(intr_handler_t handler, void *handler_arg)
{
    (void)handler;
    qemu_main_task_handle = (TaskHandle_t *)handler_arg;
    ESP_LOGI(TAG, "ULP ISR registration captured for QEMU emulation");
    return ESP_OK;
}

void __wrap_hulp_ulp_interrupt_en(void)
{
    if (!qemu_ulp_task_handle) {
        xTaskCreate(qemu_ulp_task, "qemu_ulp", 4096, NULL, 5, &qemu_ulp_task_handle);
    }
    ESP_LOGI(TAG, "ULP notifications emulated by qemu_ulp task");
}

void __wrap_init_ulp_linky(void)
{
    int frame_len = 0;
    const char *frame = qemu_selected_frame(&frame_len);

    qemu_write_frame_to_ulp_buffer(frame, frame_len);
    ESP_LOGI(TAG, "ULP Linky receiver emulated");
}

void __wrap_voltage_init(void)
{
    ESP_LOGI(TAG, "Voltage ADC emulated at %d mV", qemu_voltage_mv);
}

int __wrap_voltage_read_mv(void)
{
    return qemu_voltage_mv;
}

bool __wrap_voltage_is_low(uint16_t threshold)
{
    return qemu_voltage_mv < (int)threshold;
}

bool __wrap_voltage_is_low_dynamic(uint16_t floor_mv)
{
    return qemu_voltage_mv < (int)floor_mv;
}

void __wrap_voltage_reset_peak(void)
{
}
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

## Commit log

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2025-10-27 Fix immediate wakeup from light sleep
    [main.c]
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2026-01-28 Improve power strategy and monitoring:
    - Remove deep sleep mode
    - Init light sleep and wait for capacitor's voltage to be above a threshold to init wifi/mqtt and ulp
    - Monitor capacitor's voltage using RGB led and publish into the MQTT topic
2026-02-07 Refactor main application with FSM architecture and modular managers
    Architecture:
    - Finite State Machine (FSM) with 6 states: INIT, WAIT_VOLTAGE, WIFI_CONNECT, MQTT_CONNECT, WAIT_ULP_DATA, PUBLISH_DATA
    - Dependency injection pattern: wifi_state_t and mqtt_state_t structs owned by main, passed to manager modules
    - Shared types in types.h: conn_result_t enum (CONN_OK, CONN_FAILED, CONN_VOLTAGE_LOW) and voltage_check_fn_t callback
    - Modular design: wifi_manager and mqtt_manager handle their respective subsystems independently
    Power Management:
    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
2026-02-08 Add Home Assistant MQTT auto-discovery support
    - Single JSON state topic (<prefix>/state) instead of separate topics
    - LWT for availability (<prefix>/status with online/offline)
    - Auto-publish HA discovery configs on MQTT connect
    - Device grouped by MAC address (linkey_<mac>)
    - Sensors: Current (A), Energy Index (Wh), Supercap Voltage (mV)
2026-02-08 refactor: rename Kconfig entries from LINKY to LINKEY
    Standardize naming across all configuration options and add
    CONFIG_LINKEY_DEVICE_NAME for configurable HA device name.
2026-02-08 feat: add uptime sensor and improve HA discovery
    - Add uptime_s field to linky_data_t
    - Add state_class for proper HA statistics (total_increasing for energy/uptime, measurement for current/voltage)
    - Add custom MDI icons for all sensors
2026-02-11 refactor: use single device discovery payload for HA
    Replace per-sensor discovery with a single device discovery message
    on homeassistant/device/linkey_<mac>/config. Add FW/HW version
    macros and serial number to device info.
2026-02-11 feat: add PAPP and ADPS sensors, use HA abbreviated keys
    Add apparent power (PAPP) and overcurrent warning (ADPS) sensors.
    Fix debug logs to print parsed values instead of uninitialized data.
    Use HA abbreviated discovery keys to reduce payload size.
    [ulp_linky.cpp]
2026-02-11 docs: update README and replace TIC specification document
    Update README with HA integration, FSM architecture, new sensors
    (PAPP, ADPS, uptime), MQTT JSON topics, and project structure.
    Replace Enedis-NOI-CPT_54E with Enedis-MOP-CPT_002E specification.
2026-02-16 fix: dynamic voltage fallback and robust connection management
    - Replace fixed voltage thresholds with peak-tracking drain detection
    - Stop WiFi before MQTT to cut radio power immediately
    - Fix MQTT_EVENT_DELETED setting started=false without stopping client
    - Increase MQTT network timeout to 1500ms (exceeds modem sleep interval)
    - Add CONN_WIFI_LOST result for WiFi loss during MQTT/ULP operations
    [main.c]
2026-02-16 refactor: extract voltage management into dedicated module
    Move ADC init, voltage reading, fixed/dynamic threshold checks and
    peak tracking from main.c into voltage_manager.c/h.
    [main.c, voltage_manager.c]
2026-02-18 fix: remove emergency WiFi stop from MQTT event handler
    Let the normal FSM handle connection recovery on MQTT message expiry
    instead of killing WiFi from within the event handler.
    [main.c]
2026-02-24 refactor: replace line buffers with double-buffered frame reception
    Replace 10-16 separate line buffers (LF-terminated) with two ping-pong
    frame buffers using ETX (0x03) as UART RX termination character. Each
    reception now captures a complete TIC frame set, eliminating per-tariff
    buffer count conditionals and race conditions between ULP and CPU.
    - ULP alternates writing between buf_0 and buf_1, signaling CPU via
    ulp_active_buf which buffer to read (always the completed one)
    - CPU-side get_linky_data() parses frame by splitting on LF delimiters
    - Increase ULP_DATA_TIMEOUT_MS per tariff (3000-5000ms) to account for
    frame-level reception needing up to 2 frame periods
    - Fix CONFIG_LINKEY_TA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
    [main.c, ulp_linky.cpp]
2026-02-24 fix: support TEMPO frames >255 bytes in ULP RX buffer
    TEMPO TIC frames are ~275 bytes, exceeding both the 250-byte buffer and
    the HULP library's 8-bit metadata limit (max 255). This caused buffer
    truncation, frame misalignment, and intermittent data loss.
    - Increase LINKY_MAX_FRAME_LEN from 250 to 300
    - Replace HULP_UART_STRING_BUFFER with raw arrays (no 8-bit limit)
    - Modify ULP RX macro to use hardcoded 16-bit capacity instead of
    reading from 8-bit metadata field
    - Store received length as full 16-bit value in metadata word
    - Add custom frame_string_get() to read 16-bit length
    [ulp_linky.cpp]
2026-02-24 feat: use ULP wake ISR instead of fixed 1s polling
    Register a ULP interrupt handler that notifies the main task via
    FreeRTOS task notification when I_WAKE() fires. The CPU now sleeps
    until the ULP signals a new frame is ready, instead of polling
    every second.
    - Add ulp_isr() with vTaskNotifyGiveFromISR on ULP wake
    - ulp_wait_data() blocks on ulTaskNotifyTake instead of vTaskDelay
    - PUBLISH_DATA state blocks on notification between frames
    - Other states keep 1s periodic delay for voltage/connection checks
    [main.c]
2026-02-24 refactor: define TIC protocol bytes as LINKY_TIC_ macros
    Replace hardcoded 0x02/0x03/'\n'/'\r' with named macros and use
    LINKY_TIC_GROUP_SEP instead of isspace() for field separator matching.
    - LINKY_TIC_FRAME_START (0x02), LINKY_TIC_FRAME_END (0x03)
    - LINKY_TIC_GROUP_START (0x0A), LINKY_TIC_GROUP_END (0x0D)
    - LINKY_TIC_GROUP_SEP (0x09)
    [ulp_linky.cpp]
2026-02-24 refactor: table-driven TIC label parsing in process_message
    Replace repetitive str_starts_with/parse chains with a linky_labels[]
    descriptor table. Each entry defines: label string, expected data
    length, unit, valid flag, struct offset and field size.
    - FIELD() macro derives offset and size from the struct member
    - Single loop matches labels and stores values generically
    - Eliminates ~90 lines of duplicated parsing code
    [ulp_linky.cpp]
2026-02-25 feat: improve HA sensor display precision in MQTT discovery
    Add suggested_display_precision to all sensors (0 decimals for
    integer values). Convert energy indexes from Wh to kWh with 3
    decimal places using value_template division.
2026-04-26 Add BAS_4002A symbol into local lib
    [BAS_4002A_RPP_E6327.stp]
2026-04-26 Add B3U-1000P button footprint and 3d model
    [B3U-1000P.stp]
2026-04-26 Release PCB v1
    [LinKey.kicad_pcb, LinKey.kicad_sch]
2026-04-26 Output fab files (Gerber, NC Drill and BOM)
    [LinKey-B_Cu.gbr, LinKey-B_Mask.gbr, LinKey-B_Paste.gbr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]
2026-04-26 Update pcb version to v1.1
    - Fix R10 footprint (was 1206 but should be 0805), decrease value to increase max current to 40mA
    - Change R15/R16 values (divided by 10)
    - Increase R11 from 200r to 1k to fix voltage limitation
    - Fix I1/I2 swap
    - Modify R4, R5 values around opto
    - Add SW + Capa on EN
    [LinKey-B_Cu.gbr, LinKey-B_Mask.gbr, LinKey-B_Paste.gbr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]
2026-04-26 Fix model path for Conn_01x03 footprint in KiCad library
2026-04-26 Add 3mm light guide step
    [PLP2-3MM-D.stp]
2026-04-26 Update R11 position and J1's 3D model
    - Slightly move R11 away from the PCB edge
    - Add J1's 3D model
    - Complete J1's BOM data = Samtech vertical header that must be manually bent
    [LinKey.kicad_pcb, LinKey.kicad_sch]
2026-04-28 Remove obsolete Gerber and MCAD design files
    [Linkey_Design.FCStd]
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2026-04-29 Update Gerber and NC drill files for LinKey project v1.1
    [LinKey-B_Cu.gbr, LinKey-B_Mask.gbr, LinKey-B_Paste.gbr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]
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2026-04-29 Update PCB v1.1 to better pass DRC
    [LinKey-B_Cu.gbr, LinKey-B_Mask.gbr, LinKey-B_Paste.gbr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]
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2026-05-15 test: add host unit tests for voltage_state and CI workflow
    Set up a standalone CMake project under Firmware/test/host/ that pulls
    Unity v2.6.0 via FetchContent and builds host-side unit tests against
    the pure-logic modules. 13 cases cover voltage_state_is_low,
    voltage_state_is_low_dynamic (peak tracking, drop tolerance, floor
    clamp) and voltage_state_reset_peak.
    GitHub Actions workflow runs two jobs on every push and PR:
    - host-tests: cmake + ctest, ~30 s on ubuntu-latest
    - firmware-build: idf.py build under the espressif/idf:release-v5.4
    Docker image, as a smoke test that refactors don't break the
    production firmware build
    Documents the test layout, run recipe, and a per-module break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
2026-05-15 fix: track sdkconfig.defaults so CI gets ULP/PM config
2026-05-15 refactor: extract tic_parser from ulp_linky
    Move the pure-C TIC parsing (checksum, group parsing, label dispatch)
    out of ulp_linky.cpp into a new host-testable tic_parser module,
    mirroring the voltage_state pattern. Shared types move into
    tic_types.h; ulp_linky.cpp keeps the ULP/RTC layer only.
    Bundled fix: debug.h includes esp_log.h only when debug logs are
    enabled, so logic files compile on host with no stubs.
    [ulp_linky.cpp]
2026-05-15 test: add host unit tests for tic_parser
    25 Unity cases: checksum validation (incl. one hand-computed reference
    to pin the (sum & 0x3F) + 0x20 formula), single-group parsing for each
    supported label and its rejection paths, and full-frame parsing
    (happy path, bad-checksum skip, unknown labels, malformed frames).
    [test_tic_parser.c]
2026-05-16 ci: add KiCad DRC and fab file generation jobs
    Drop the committed Gerber/drill outputs since CI now produces them as
    artifacts from the source .kicad_pcb on every push.
    [LinKey-B_Cu.gbr, LinKey-B_Mask.gbr, LinKey-B_Paste.gbr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]
2026-05-16 ci: drive fab generation from kicad jobset
    Use kicad-cli jobset so layer/output selection lives in the project
    instead of being duplicated in YAML. Document the resulting CI artifact
    contents in PCB/README.md, ignore the generated fab-output/ folder, and
    drop the manually exported BOM CSV (now produced by CI).
    [LinKey.csv]
2026-05-17 docs: add 3D casing v2 design and CAO documentation
    Version the Onshape-sourced STEP and add CAO/README with the Onshape
    link, print parameters, and a Releases-hosted STL/3MF download table.
    Surface the new section in the root README and replace stale PCB
    Gerber/BOM links (now CI artifacts) with a single note pointing at the
    CI artifact and tagged Releases.
    [Linkey-boitier-v2.step]
2026-05-17 refactor(pcb): derive PCB version from git tag pcb-v*
    - CI computes version via 'git describe --tags --match pcb-v*' and
    injects it into text_variables.PCB_VERSION in LinKey.kicad_pro before
    running the jobset, so silkscreen ${PCB_VERSION} reflects the build
    - fetch-depth: 0 on checkout so describe sees tags
    - Artifact name LinKey-pcb-<version>-fab (e.g. v1.0, or v1.0-N-gSHA off-tag)
    - Local kicad_pro pins PCB_VERSION to UNCONTROLLED to flag manual exports
    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
    [LinKey.kicad_pcb]
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2026-05-17 test: extend host test edge cases for tic_parser and voltage_state
    tic_parser (+5):
    - null group pointer safety mirror of existing null-data test
    - value shorter than expected (consumed-length mismatch)
    - non-digit byte in value rejected by parse_uint length check
    - extra separators between label and value tolerated
    - null frame pointer safety
    - 2-byte STX+LF frame returns 0
    - stray bytes between STX and first LF walked over harmlessly
    voltage_state (+5):
    - is_low with negative reading (transient ADC glitch must trip watchdog)
    - is_low_dynamic exact-boundary at peak - drop_mv (strict less-than)
    - is_low_dynamic with zero or negative voltage
    - is_low_dynamic with floor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
    [test_tic_parser.c]
2026-05-17 refactor(fsm): extract pure FSM transition logic into main/fsm.{h,c}
    Each handle_state_* handler keeps its IDF/side-effect calls; the post-call
    switch on conn_result_t (and the per-iteration watchdog + peak-reset rules
    in app_main) move to fsm.{h,c} as pure functions. app_state_t moves to
    fsm.h so tests can use it. Handler behavior, call ordering and log lines
    are preserved.
    test: add test_main_fsm covering all 6 pure functions
    27 Unity tests exercise every FSM transition rule, the precedence chain
    in fsm_after_publish_data, the watchdog skip-state passthroughs, and the
    peak-reset state set. Host tests now total 77 (voltage_state 18,
    tic_parser 32, main_fsm 27).
    [main.c]
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2026-05-27 Add QEMU firmware emulation target
    - add QEMU emulation component with hardware wrappers for ULP, voltage, WiFi, and power
    management
    - add deterministic TIC test frames for BASE, HPHC, EJP, and TEMPO tariffs
    - add run_qemu_linkey.sh with --tariff_option support and tariff-specific build dirs
    - add QEMU sdkconfig defaults and local Mosquitto broker config
    - document QEMU build, launch, MQTT broker, and validation workflow
    - ignore generated QEMU build directories
    [linkey_qemu_mocks.c, qemu_test_data.h]
2026-05-31 ci: validate QEMU MQTT emulation
    Replace the QEMU boot smoke test with tariff-based MQTT emulation checks.
    - Run QEMU CI across base, hphc, ejp, and tempo tariffs
    - Start a local Mosquitto broker and capture MQTT traffic
    - Validate online status, Home Assistant discovery, and state topics
    - Add MQTT assertion helper for tariff-specific discovery components
    - Use deterministic QEMU WiFi STA MAC AA:BB:CC:DD:EE:FF
    - Wrap esp_read_mac only for QEMU emulation builds
    [assert_mqtt.py, linkey_qemu_mocks.c]
2026-05-31 docs: add images for Home Assistant device discovery and sensor information
    Fix a minor typo.
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2026-07-26 Corrections mineures : - valeur C5 : 15 pF -> 180 pF cohérente avec la référence composant - tension R10 : 75 V -> 150 V cohérente avec la référence composant
    [LinKey.kicad_sch]
2026-07-26 PCB : Modification du modèle 3D et de la position de C2 (supercapa). Couchée orientée pour ne pas interférer avec les autres composants.
    [Capacitor_THT-CP_Radial_D8.0mm_P3.50mm_special_position - Capacitor_THT-CP_Radial_D8.0mm_P3.50mm_special_position.step, LinKey.kicad_pcb]
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2026-08-06 provisioning: add low-power BLE WiFi setup
    Add a BLE provisioning FSM state that starts when no WiFi credentials are stored.
    Store credentials through the standard Espressif provisioning app without running immediate WiFi validation.
    Replace WiFi scan requests with an empty low-power scan endpoint because scanning is not supportable on the power budget.
    Print the provisioning URL and emit the terminal QR code only in debug builds.
    [main.c]
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2026-08-07 Add GPIO0 manual WiFi provisioning trigger
    Poll the BOOT button from the existing FSM loop so long-press detection does not add an always-running task or extra wakeups.
    Enter BLE provisioning after GPIO0 is held for at least two seconds, and require release before accepting another trigger.
    Keep existing WiFi credentials when manual provisioning fails so stored credentials are only replaced after the provisioning app submits new ones.
    [main.c]
2026-08-07 Move initialization out of the runtime FSM
    Run NVS, LED, ADC, and power-management initialization once before entering the main state loop so INIT no longer participates in state LED blinking.
    Remove STATE_INIT from the pure FSM model and update voltage watchdog tests to reflect that WAIT_VOLTAGE is now the first runtime state.
    Update the firmware README diagram, state table, and test description to match the init-plus-FSM boot flow.
    [main.c]
2026-08-07 Fix QEMU provisioning trigger emulation
    Keep normal QEMU runs out of the manual provisioning path by wrapping GPIO0 as released by default and by mocking wifi_has_config() instead of calling the real WiFi driver state API.
    Exclude the real BLE provisioning implementation from QEMU builds and provide an emulation stub so manual provisioning requests can be observed without pulling in unsupported BLE runtime behavior.
    Add a manual provisioning QEMU mode, build-only support in the runner, a CI job, and a log assertion that verifies the simulated BOOT long press reaches the provisioning stub without panic/assert markers.
    [assert_manual_provisioning.py, linkey_qemu_mocks.c]
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2026-08-09 Add factory NVS secret support
    Add a factory_data NVS partition and a shared factory_config_schema.h that owns the factory partition label, namespace, NVS key names, and development fallback secrets.
    Read MQTT password and BLE provisioning PoP from the factory partition when available, with empty Kconfig values acting only as development overrides instead of owning defaults.
    Keep normal firmware logs from printing provisioning credentials; QR/provisioning URL output remains debug-log only.
    [partitions.csv]
2026-08-09 Add factory flash setup tool
    Add a Python factory flashing tool that reads the ESP32 MAC, generates or reuses per-device MQTT and BLE provisioning secrets, creates the factory NVS image, flashes factory_data, and prints install information for Home Assistant/provisioning.
    Read the factory schema from factory_config_schema.h so the Python tool does not duplicate partition, namespace, key, or fallback definitions.
    Keep the ESP32 in ROM bootloader after MAC read and flash factory_data before the final firmware flash, avoiding a second manual BOOT/reset cycle on boards without reliable auto-boot.
    Ignore generated per-device factory files and the isolated build-factory directory.
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2026-08-09 Require MQTT credentials in QEMU tests
    Configure CI Mosquitto to reject anonymous clients and require the deterministic QEMU credentials linkey_ddeeff / mqtt-password, matching the mocked MAC suffix and factory schema fallback.
    Authenticate CI probe, subscription capture, and debug request publishing so the smoke test fails if firmware MQTT auth regresses.
    Align the local Docker Mosquitto setup and emulation docs with the same credential-gated broker behavior.
    Add a lightweight CI validation step for factory_flash.py schema parsing so schema/header changes cannot silently break the factory tool.
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2026-09-07 Generate quick start guide during factory flash
    - Add a two-sided quick start guide HTML template with Linkey branding, provisioning QR placement, and MQTT credential placeholders.
    - Extend factory_flash.py to generate per-device quick_start.html and quick_start.pdf next to the existing setup text file.
    - Resolve logo and app badge assets to local file URIs before PDF rendering so headless Chrome embeds them reliably.
    - Include local Google Play and App Store badge assets and add --chrome / --no-guide-pdf controls for the generator.

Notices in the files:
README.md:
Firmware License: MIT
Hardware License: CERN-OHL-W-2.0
